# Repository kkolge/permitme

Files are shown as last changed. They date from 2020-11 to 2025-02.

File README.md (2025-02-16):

This product was developed during COVID-19 to 
1. Screen a large number of people based on 3 parameters - Temperature, Pulse Rate and SpO2
2. The purpose was to create a funnel where a large number of people can be screened in a short time so that probably infected people could be provided with a better care
3. The system uses this device as an IoT based data collection unit
4. It stored the data on a backend server which can be then checked during the next screening

The hardware system was developed in C, C++ and the web application was developed in PHP. 

Though this system was deployed at 30+ locations, it could not be scaled up due to delay in approvals during COVID. 

Unfortunately the Unit and Integration tests were lost in a system crash and are not part of the repository

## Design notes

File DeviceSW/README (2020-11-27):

This folder contains source code for the permit me device

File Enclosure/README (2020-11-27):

This folder contains Design files for the enclosure

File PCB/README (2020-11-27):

This folder contains KiCad Project for PCB

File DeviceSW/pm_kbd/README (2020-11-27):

This folder contains code for Keyboard device

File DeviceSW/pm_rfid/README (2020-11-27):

This folder contains code for permit me device with rfid reader

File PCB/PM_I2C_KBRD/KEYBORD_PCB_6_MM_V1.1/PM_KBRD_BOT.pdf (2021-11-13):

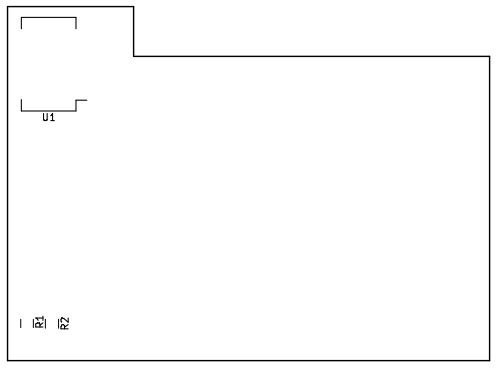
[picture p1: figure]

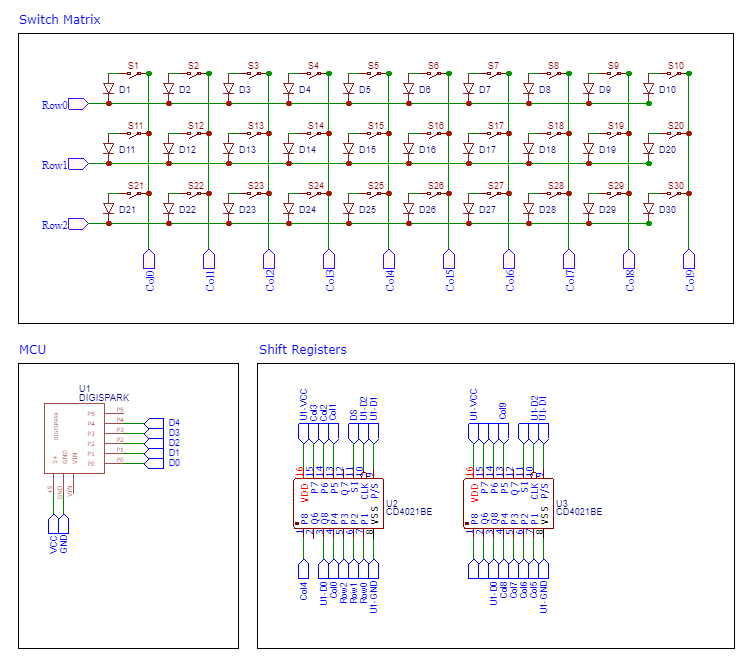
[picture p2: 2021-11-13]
PCB/PM_I2C_KBRD/KEYBORD_PCB_12MM_V4/F7GHN2HKNOLY77V.webp

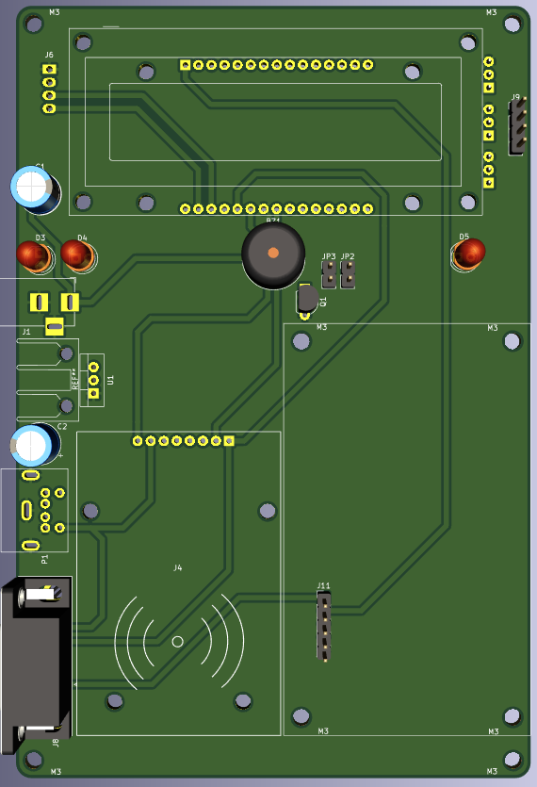
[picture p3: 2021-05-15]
PCB/Screenshot from 2020-12-09 14-33-55.png

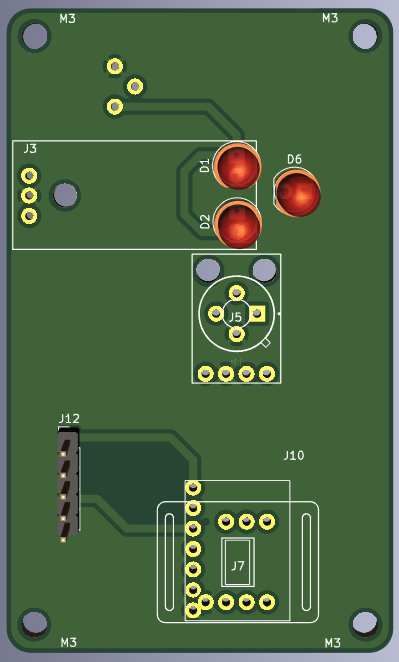
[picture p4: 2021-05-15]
PCB/Screenshot from 2020-12-09 14-36-24.png

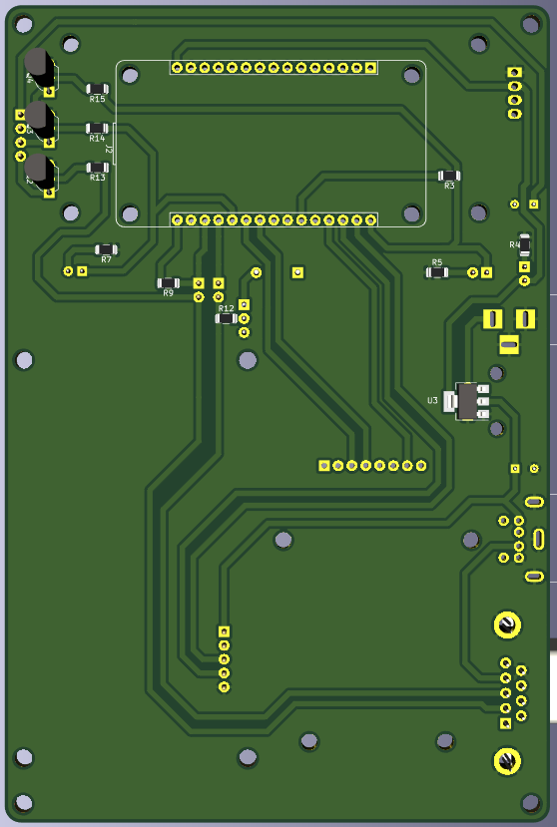
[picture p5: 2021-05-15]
PCB/Screenshot from 2020-12-09 14-34-07.png

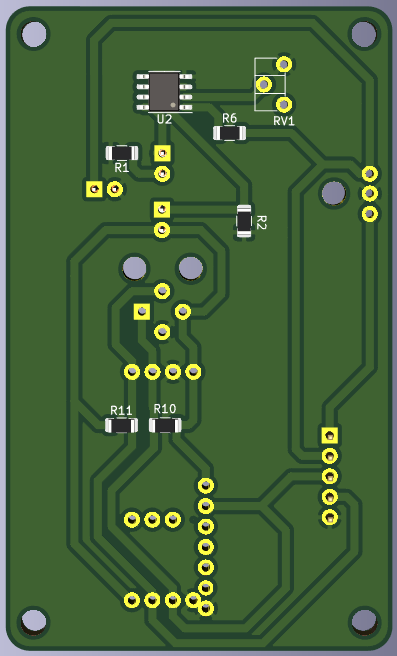
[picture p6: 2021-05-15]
PCB/Screenshot from 2020-12-09 14-36-14.png

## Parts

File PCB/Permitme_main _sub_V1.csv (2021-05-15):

Id | Designator | Package | Quantity | Designation
1 | BZ1 | Buzzer_12x9.5RM7.6 | 1 | 5V Buzzer
2 | C1 | CP_Radial_D8.0mm_P3.50mm | 1 | 100uf 16V
3 | C2 | CP_Radial_D8.0mm_P3.50mm | 1 | 470uf 16V
4 | D1 | LED_D5.0mm | 1 | IR_TX
5 | D2 | LED_D5.0mm | 1 | IR_RX
6 | D4 | LED_D5.0mm | 1 | RED LED 5MM
7 | D5 | LED_D5.0mm | 1 | GREEN LED 5MM
8 | J1 | BarrelJack_Horizontal | 1 | DC Barrel_Jack_Switch
9 | J11 | PinHeader_1x05_P2.54mm_Vertical | 1 | Female Burg Strip
10 | J12 | PinHeader_1x05_P2.54mm_Vertical | 1 | Male Burg Strip
11 | J2 | NODEMCU_LOLIN_V3 | 1 | ESP8266 Module
12 | J5 | MLX90614 | 1 | MLX90614
13 | J6 | WC1602A_I2C | 1 | I2C LCD
14 | J7 | MAX30102 | 1 | MAX30102
15 | JP2,JP3 | PinHeader_1x02_P2.54mm_Vertical | 2 | Jumper
16 | Q1 | TO-92L_Inline_Wide | 1 | BC548
17 | R1 | R_1206_3216Metric | 1 | 100E
18 | R11,R10 | R_1206_3216Metric | 2 | 220E
19 | R12 | R_1206_3216Metric | 1 | 1K
20 | R2 | R_1206_3216Metric | 1 | 10K
21 | R7,R3,R9,R5,R4,R6 | R_1206_3216Metric | 6 | 330E
22 | REF** | Heatsink16by35 | 1 | Heatsink16by35
23 | RV1 | Potentiometer_ACP_CA6-H2,5_Horizontal | 1 | 10K
24 | U2 | SOIC-8_3.9x4.9mm_P1.27mm | 1 | LM358
25 | P1 | Connector_Mini-DIN_Female_6Pin_2rows | 1 | PS2 FEMALE – 6pins
 |  | OR
 | J4 | RFID_MFRC522 | 1 | MFRC522
26 | U1 | TO-220-3_Vertical | 1 | LM1117-5.0
 |  | OR
 | U3 | SOT-223-3_TabPin2 | 1 | LM1117-5.0
 | Optinal
27 | D3,D6 | LED_D5.0mm | 2 | LED
28 | R14,R13,R15 | R_1206_3216Metric | 3 | 1K
29 | Q4,Q1,Q3,Q2 | TO-92L_Inline_Wide | 3 | BC548
30 | J8 | DSUB-9_Female_Horizontal | 1 | DB9_Female_MountingHoles

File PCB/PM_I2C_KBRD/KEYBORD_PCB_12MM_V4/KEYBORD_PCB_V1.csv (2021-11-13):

Id | Designator | Package | Quantity | Designation | Supplier and ref
1 | D1,D2,D3,D4,D5,D6,D7,D8 | D_DO-35_SOD27_P7.62mm_Horizontal | 8 | 1N4148
2 | J1 | PinSocket_1x08_P2.54mm_Vertical | 1 | Conn_01x08_Male
3 | R1,R2,R3,R4 | R_1206_3216Metric_Pad1.42x1.75mm_HandSolder | 4 | 5.6K
4 | R5 | R_1206_3216Metric_Pad1.42x1.75mm_HandSolder | 1 | 56K
5 | SW1 | SW_PUSH_6mm_H5mm | 1 | 1
6 | SW2 | SW_PUSH_6mm_H5mm | 1 | 4
7 | SW3 | SW_PUSH_6mm_H5mm | 1 | 7
8 | SW4 | SW_PUSH_6mm_H5mm | 1 | CLEAR
9 | SW5 | SW_PUSH_6mm_H5mm | 1 | 2
10 | SW6 | SW_PUSH_6mm_H5mm | 1 | 5
11 | SW7 | SW_PUSH_6mm_H5mm | 1 | 8
12 | SW8 | SW_PUSH_6mm_H5mm | 1 | 0
13 | SW9 | SW_PUSH_6mm_H5mm | 1 | 3
14 | SW10 | SW_PUSH_6mm_H5mm | 1 | 6
15 | SW11 | SW_PUSH_6mm_H5mm | 1 | 9
16 | SW12 | SW_PUSH_6mm_H5mm | 1 | ENTER
17 | U1 | SOIC-16_3.9x9.9mm_P1.27mm | 1 | 74HC595

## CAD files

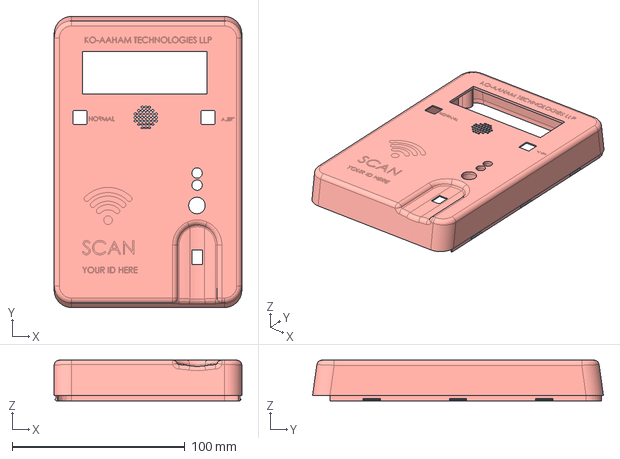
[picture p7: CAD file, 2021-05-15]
Enclosure/IDEMI/V4/outer_cover_ko-aham_tech_4.stp
108.7 x 168.6 x 23.6 mm

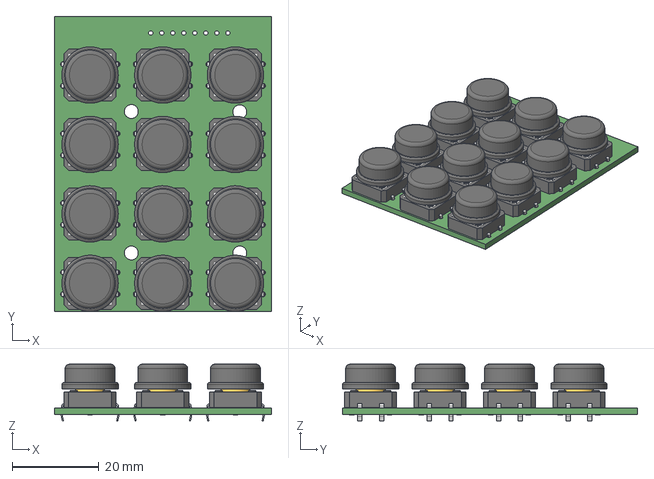
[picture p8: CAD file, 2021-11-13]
PCB/PM_I2C_KBRD/KEYBORD_PCB_12MM_V4/KEYBORD_PCB_V1.step
50.0 x 68.0 x 13.0 mm

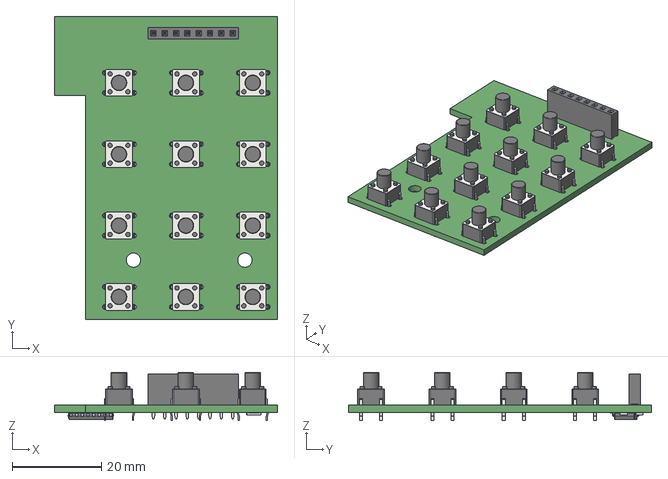
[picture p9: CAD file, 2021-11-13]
PCB/PM_I2C_KBRD/KEYBORD_PCB_6_MM_V1.1/EXPORT/STEP/KEYBORD_PCB_V1.step
50.0 x 68.0 x 10.8 mm

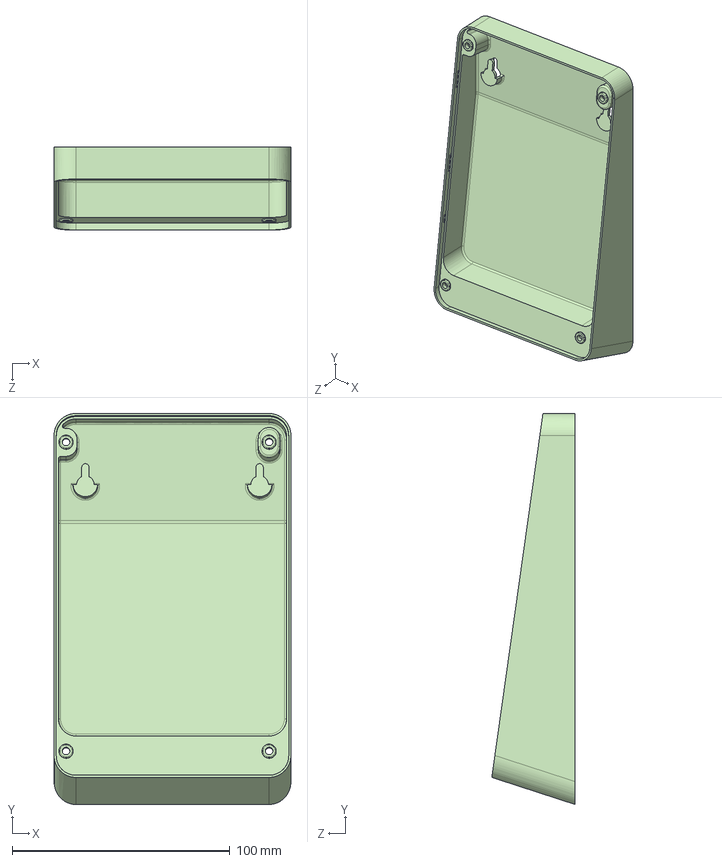
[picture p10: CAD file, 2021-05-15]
Enclosure/IDEMI/V4/back_cover_ko-aham_tech_4.IGS
108.7 x 179.4 x 38.3 mm

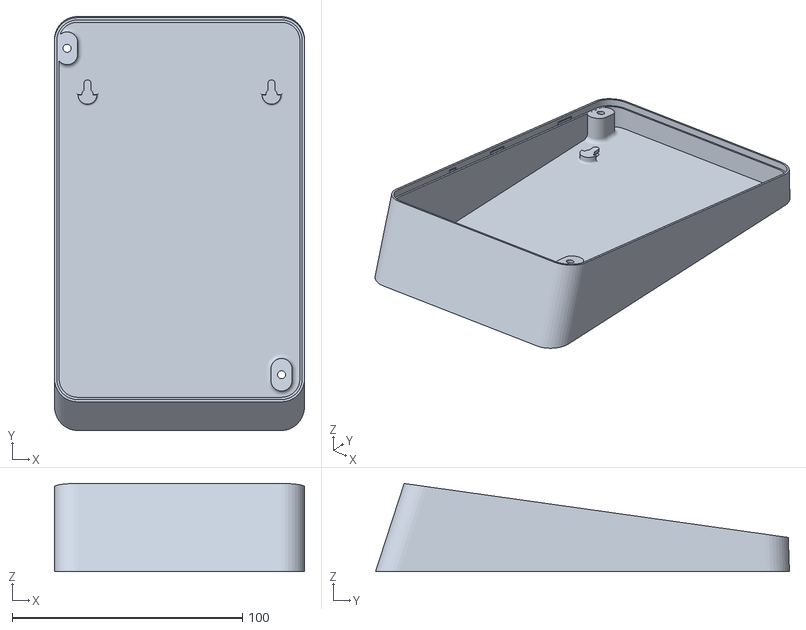
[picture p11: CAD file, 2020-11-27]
Enclosure/IDEMI/V4/KOAHAM D8.1 - BACK COVER KO-AHAM TECH 4-1.STL
108.7 x 180.0 x 38.3

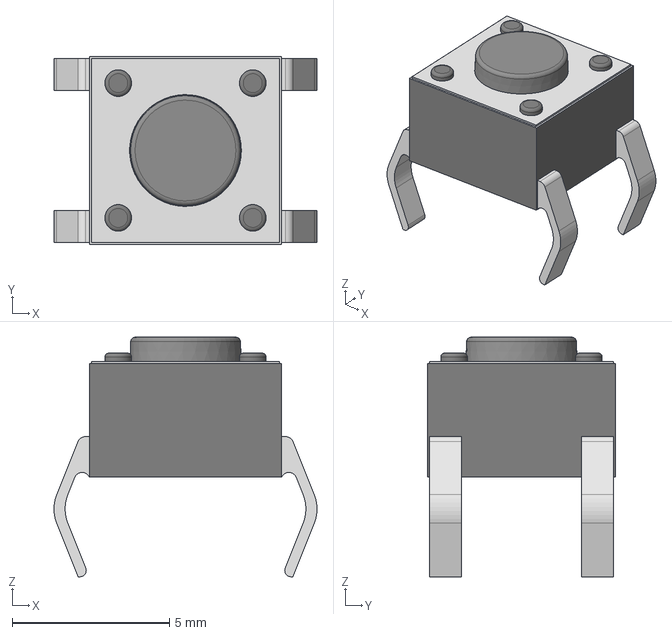
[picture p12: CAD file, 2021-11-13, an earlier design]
PCB/PM_I2C_KBRD/KEYBORD_PCB_6_MM_V1/3D/tactile-switch-thru-6mm-series-1.snapshot.25/Tactal Switch -Thru (6mmx 6mmx4.5mm).stp
8.37 x 5.99 x 7.62 mm

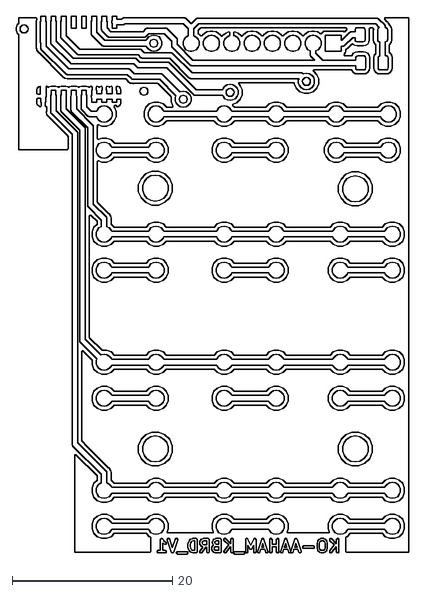
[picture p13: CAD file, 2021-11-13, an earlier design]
PCB/PM_I2C_KBRD/KEYBORD_PCB_6_MM_V1/Gurber-dxf/KEYBORD_PCB_V1-B.Cu.dxf
49.1 x 67.2

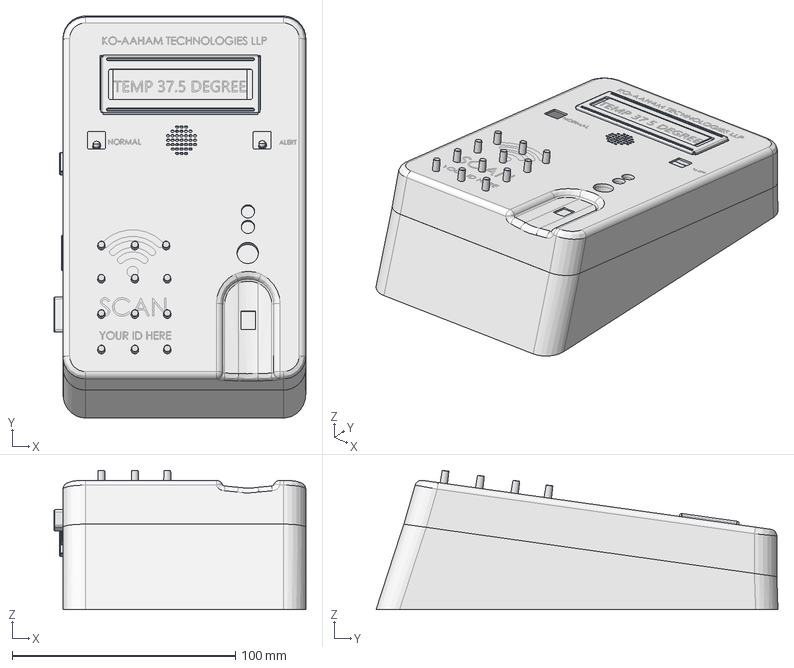
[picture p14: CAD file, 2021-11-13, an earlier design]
PCB/PM_I2C_KBRD/KEYBORD_PCB_6_MM_V1/OLD EXPORT/new keypad_/new keypad with encloser.FCStd
112.6 x 180.0 x 62.4 mm
BACK COVER KO-AHAM TECH 4
OUTER COVER KO-AHAM TECH 4
TEMPRATURE PLATE
SOLID.step
SOLID001.step
SOLID002.step
SOLID003.step
SOLID004.step
SOLID006.step
SOLID007.step
SOLID008.step
SOLID009.step
SOLID010.step
SOLID011.step
SOLID012.step
SOLID013.step
SOLID014.step
SOLID015.step
SOLID016.step
SOLID017.step
SOLID018.step
SOLID019.step
SOLID020.step
SOLID021.step
SOLID022.step
SOLID023.step
SOLID024.step
SOLID025.step
SOLID026.step
SOLID028.step
SOLID029.step
COMPOUND.step
13-FreeParts

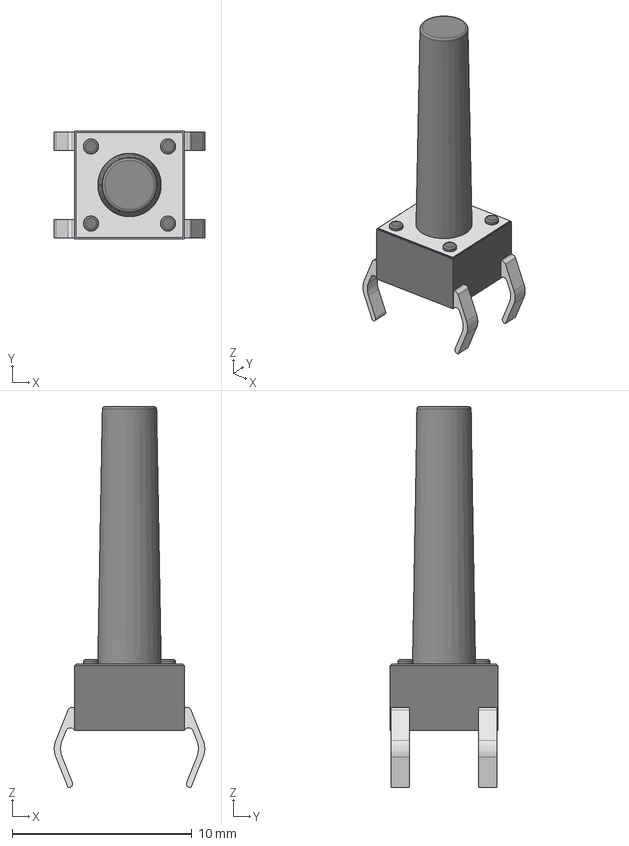
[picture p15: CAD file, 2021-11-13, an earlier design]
PCB/PM_I2C_KBRD/KEYBORD_PCB_6_MM_V1/3D/tactile-switch-thru-6mm-series-1.snapshot.25/Tactal Switch -Thru (6mmx 6mmx18.0mm).stp
8.37 x 5.99 x 21.2 mm

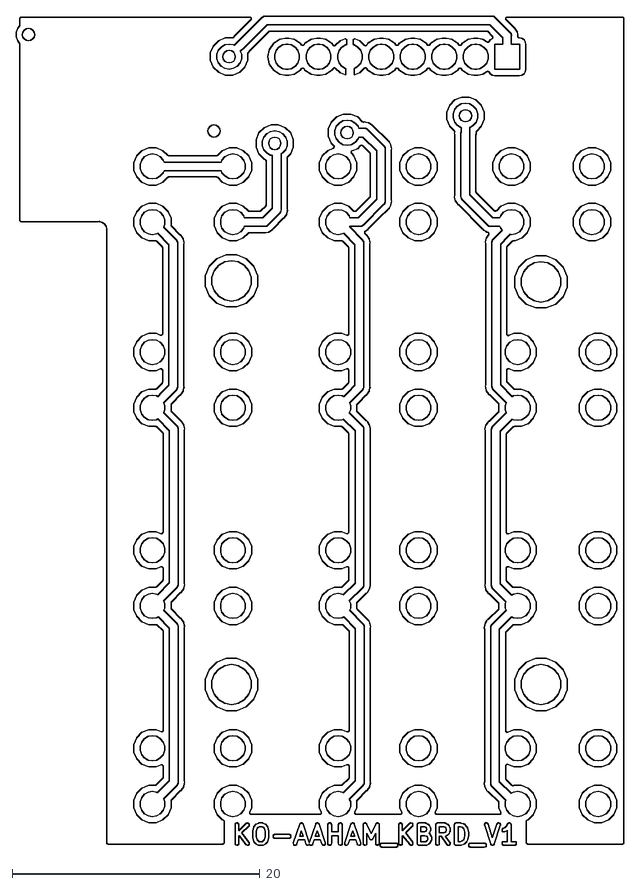
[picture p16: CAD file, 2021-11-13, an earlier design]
PCB/PM_I2C_KBRD/KEYBORD_PCB_6_MM_V1/Gurber-dxf/KEYBORD_PCB_V1-F.Cu.dxf
49.1 x 67.1

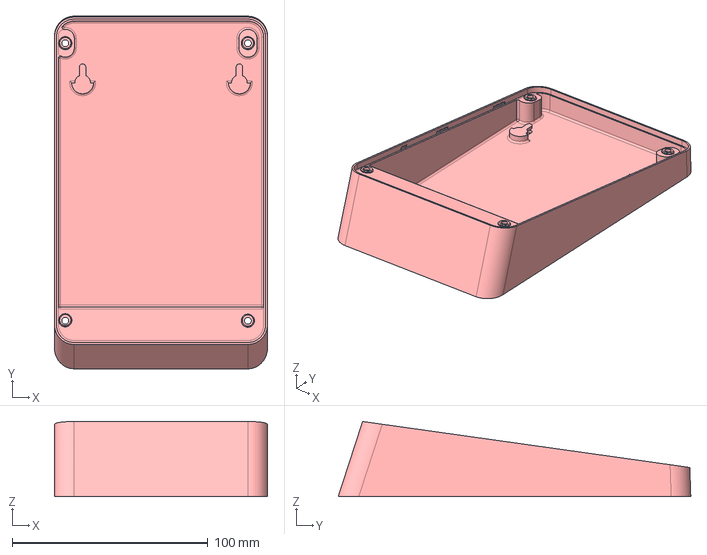
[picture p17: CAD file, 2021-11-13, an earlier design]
PCB/PM_I2C_KBRD/KEYBORD_PCB_6_MM_V1/OLD EXPORT/BACK COVER .stp
108.7 x 180.0 x 38.3 mm

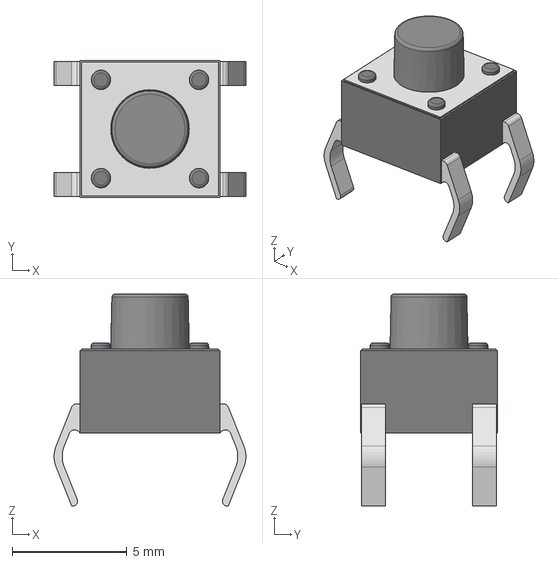
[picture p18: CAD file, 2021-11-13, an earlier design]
PCB/PM_I2C_KBRD/KEYBORD_PCB_6_MM_V1/3D/tactile-switch-thru-6mm-series-1.snapshot.25/Tactal Switch -Thru (6mmx 6mmx6.0mm).stp
8.37 x 5.99 x 9.25 mm

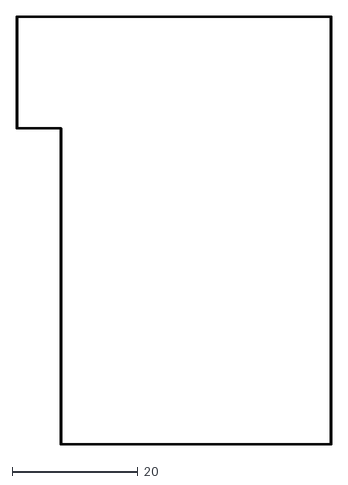
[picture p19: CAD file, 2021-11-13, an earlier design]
PCB/PM_I2C_KBRD/KEYBORD_PCB_6_MM_V1/Gurber-dxf/KEYBORD_PCB_V1-Edge.Cuts.dxf
50.2 x 68.2

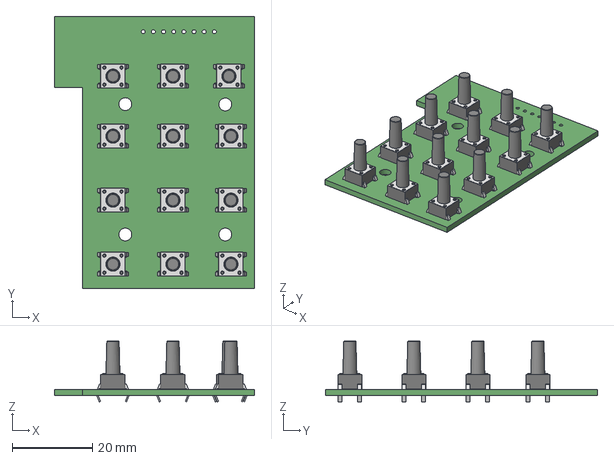
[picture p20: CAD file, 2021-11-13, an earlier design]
PCB/PM_I2C_KBRD/KEYBORD_PCB_6_MM_V1/OLD EXPORT/KEYBORD_PCB_V1.step
50.0 x 68.0 x 15.2 mm

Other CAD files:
PCB/PM_I2C_KBRD/KEYBORD_PCB_6_MM_V1/EXPORT/KEYBORD_PCB_V1.step
PCB/PM_I2C_KBRD/KEYBORD_PCB_6_MM_V1/OLD EXPORT/OUTER COVER.stp
PCB/PM_I2C_KBRD/KEYBORD_PCB_6_MM_V1/3D/tactile-switch-thru-6mm-series-1.snapshot.25/Tactal Switch -Thru (6mmx 6mmx14.0mm).stp
PCB/PM_I2C_KBRD/KEYBORD_PCB_6_MM_V1/3D/tactile-switch-thru-6mm-series-1.snapshot.25/Tactal Switch -Thru (6mmx 6mmx4.3mm).stp
Enclosure/IDEMI/V4/back_cover_ko-aham_tech_4.STL
Enclosure/IDEMI/V4/outer_cover_ko-aham_tech_4.stl
PCB/PM_I2C_KBRD/KEYBORD_PCB_6_MM_V1/3D/tactile-switch-thru-6mm-series-1.snapshot.25/Tactal Switch -Thru (6mmx 6mmx10.0mm).stp
PCB/PM_I2C_KBRD/KEYBORD_PCB_6_MM_V1/3D/tactile-switch-thru-6mm-series-1.snapshot.25/Tactal Switch -Thru (6mmx 6mmx11.0mm).stp
PCB/PM_I2C_KBRD/KEYBORD_PCB_6_MM_V1/3D/tactile-switch-thru-6mm-series-1.snapshot.25/Tactal Switch -Thru (6mmx 6mmx12.0mm).stp
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

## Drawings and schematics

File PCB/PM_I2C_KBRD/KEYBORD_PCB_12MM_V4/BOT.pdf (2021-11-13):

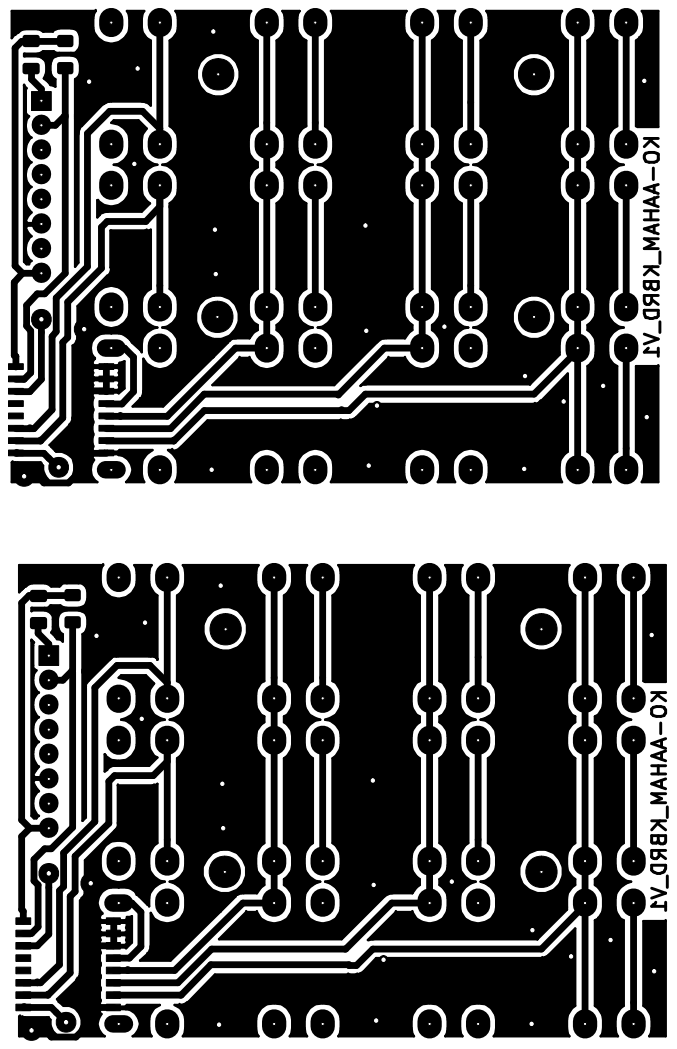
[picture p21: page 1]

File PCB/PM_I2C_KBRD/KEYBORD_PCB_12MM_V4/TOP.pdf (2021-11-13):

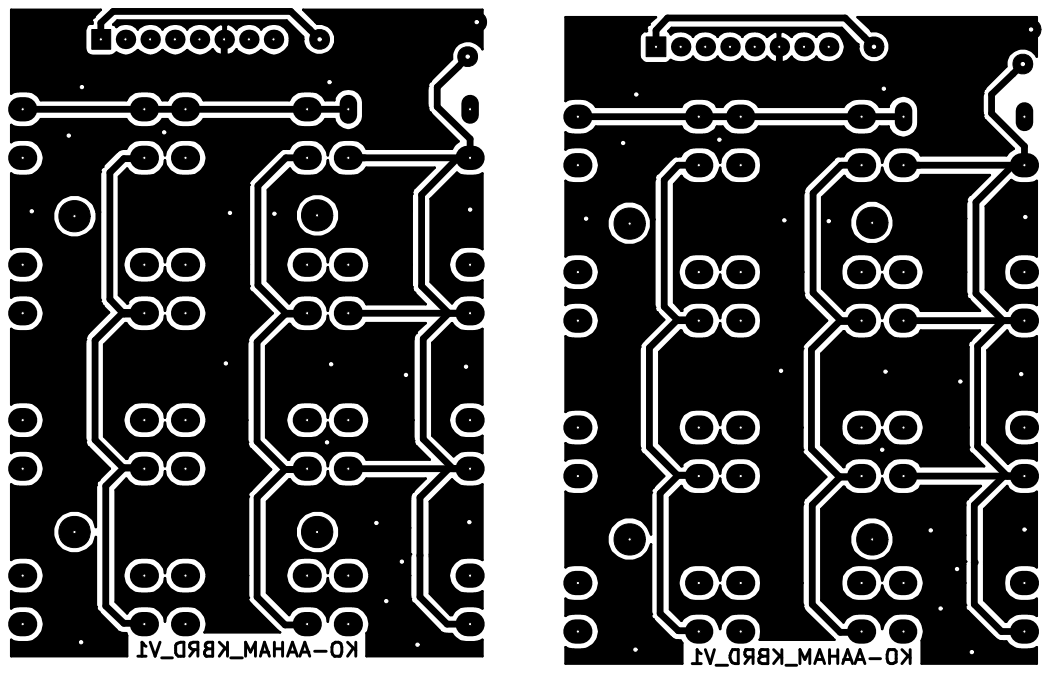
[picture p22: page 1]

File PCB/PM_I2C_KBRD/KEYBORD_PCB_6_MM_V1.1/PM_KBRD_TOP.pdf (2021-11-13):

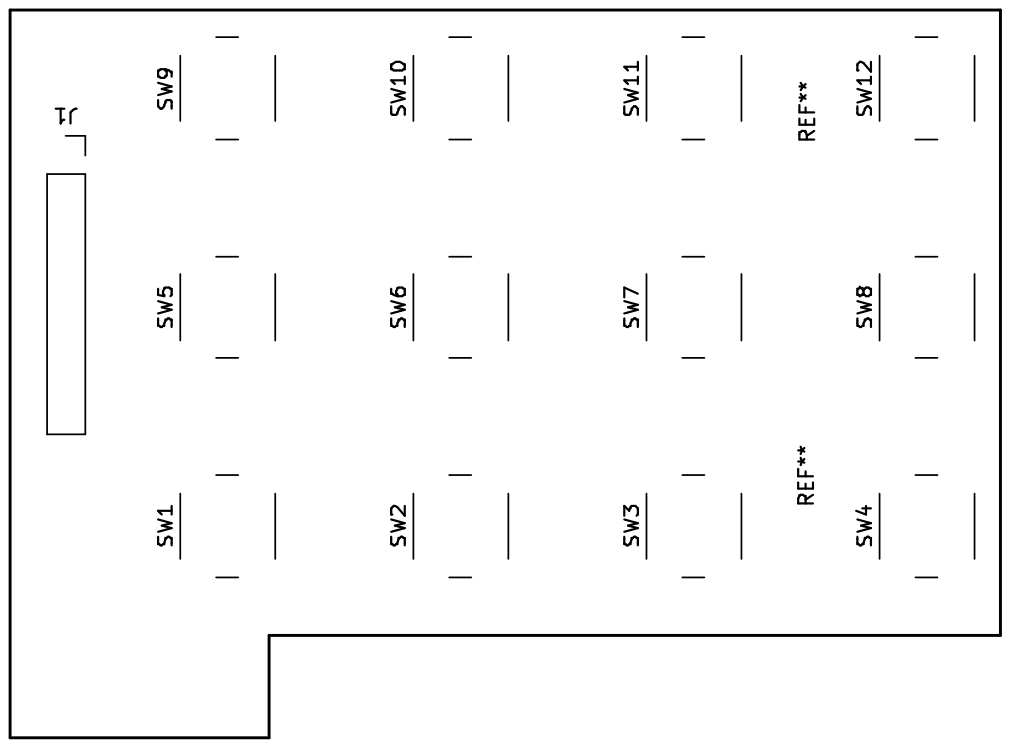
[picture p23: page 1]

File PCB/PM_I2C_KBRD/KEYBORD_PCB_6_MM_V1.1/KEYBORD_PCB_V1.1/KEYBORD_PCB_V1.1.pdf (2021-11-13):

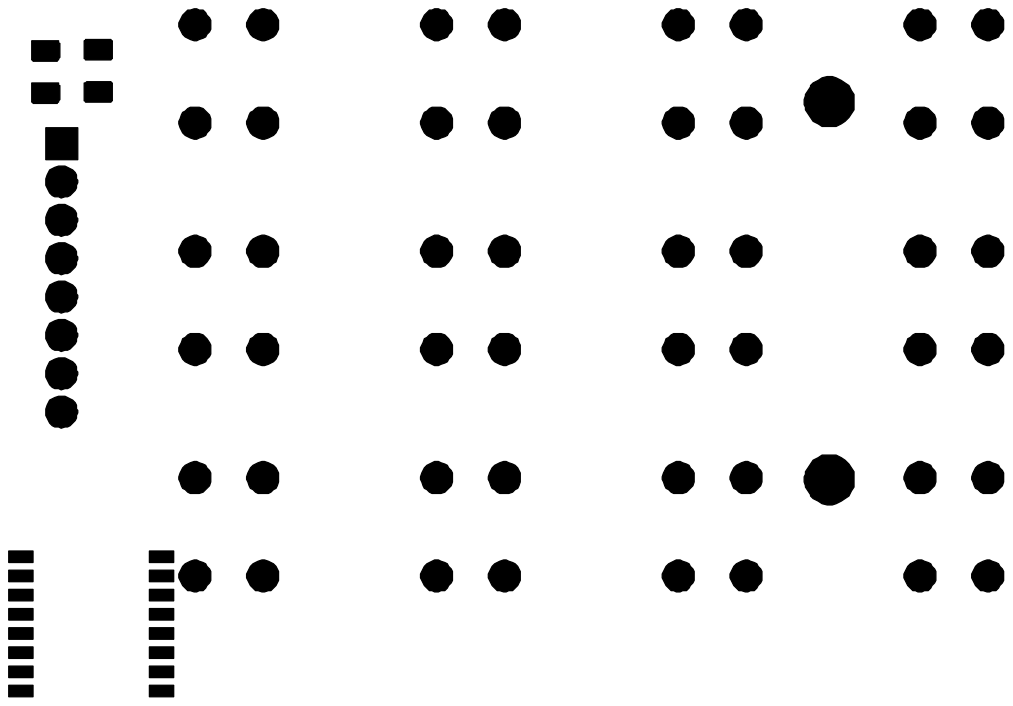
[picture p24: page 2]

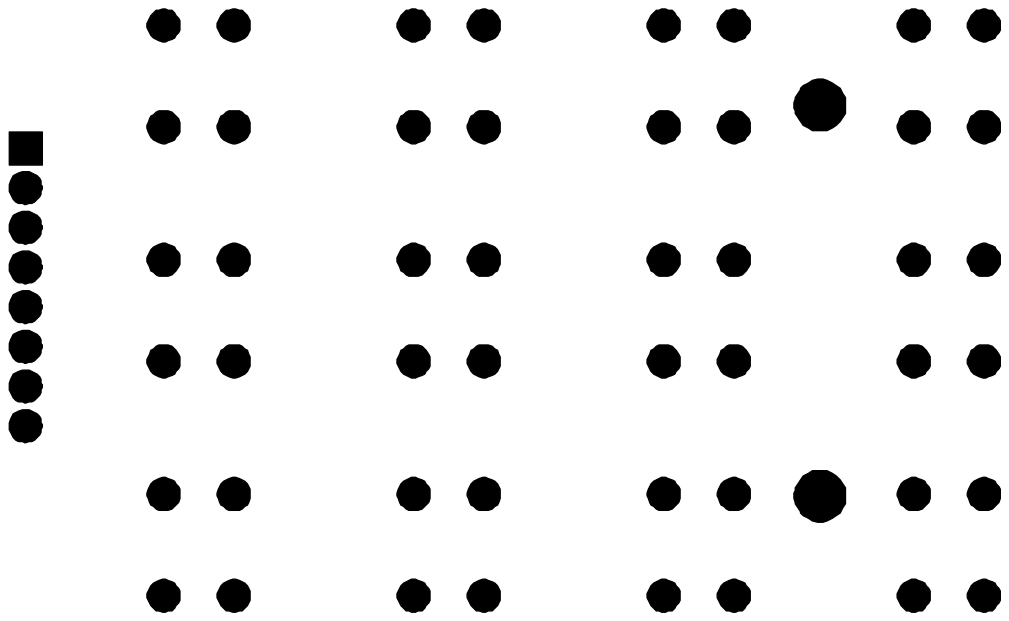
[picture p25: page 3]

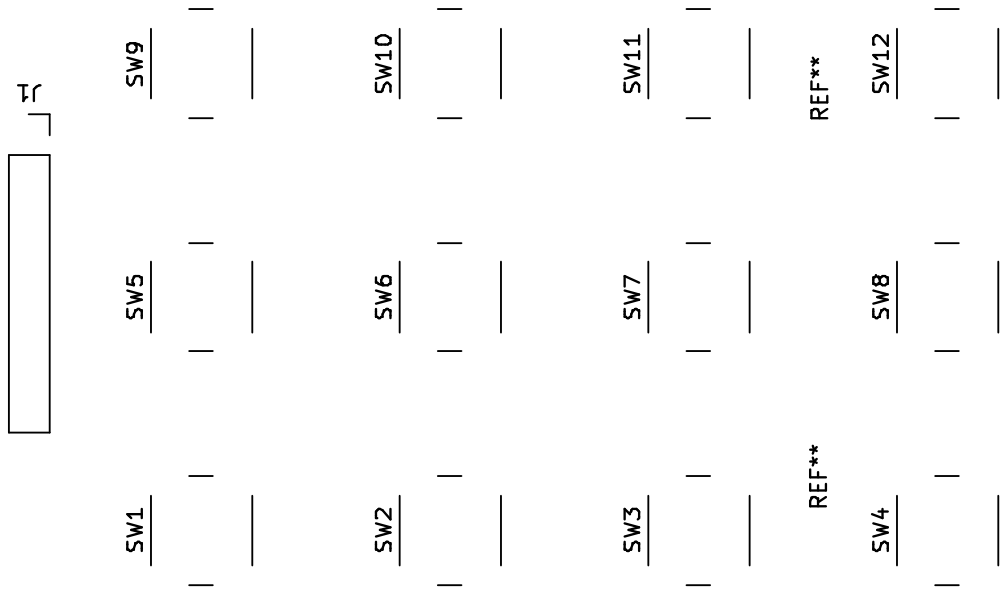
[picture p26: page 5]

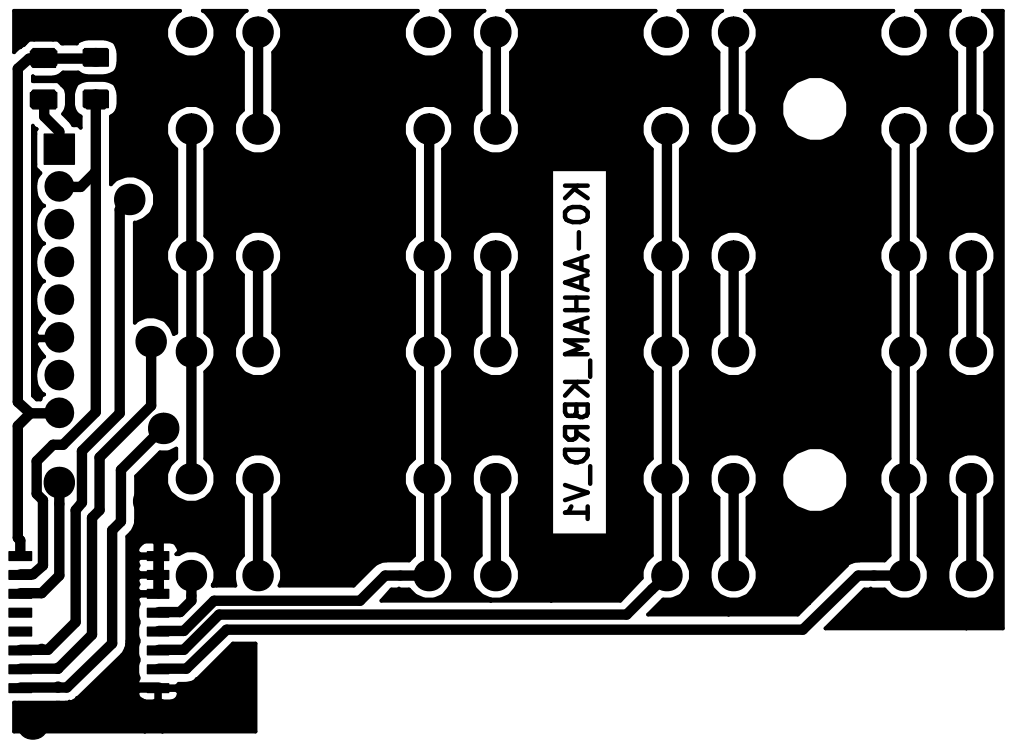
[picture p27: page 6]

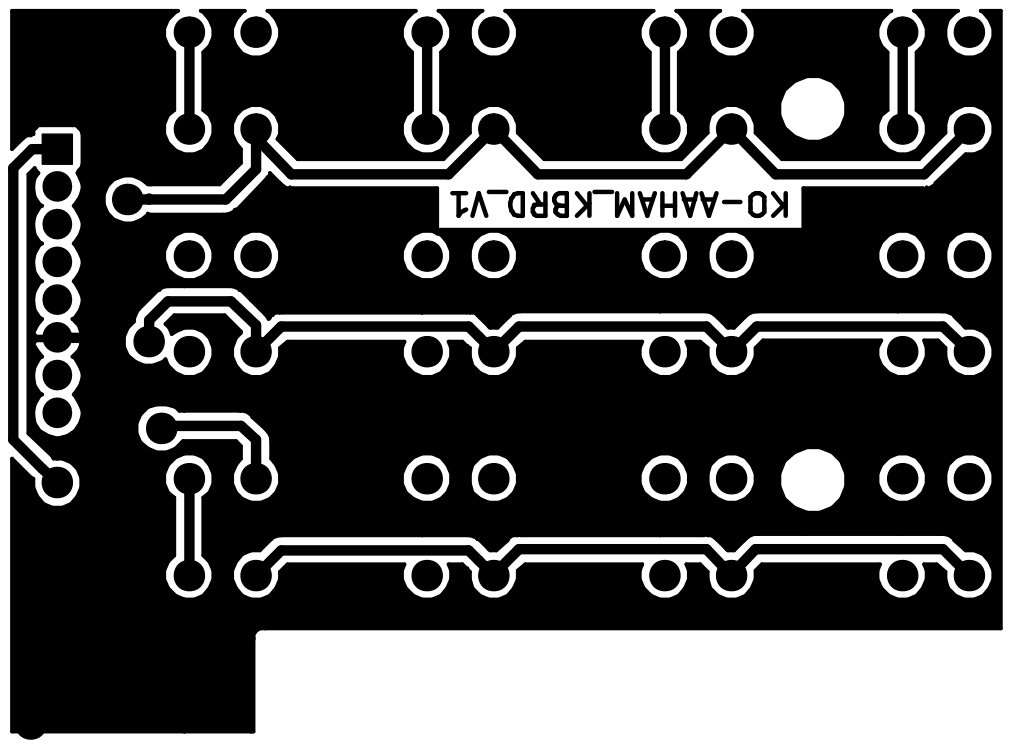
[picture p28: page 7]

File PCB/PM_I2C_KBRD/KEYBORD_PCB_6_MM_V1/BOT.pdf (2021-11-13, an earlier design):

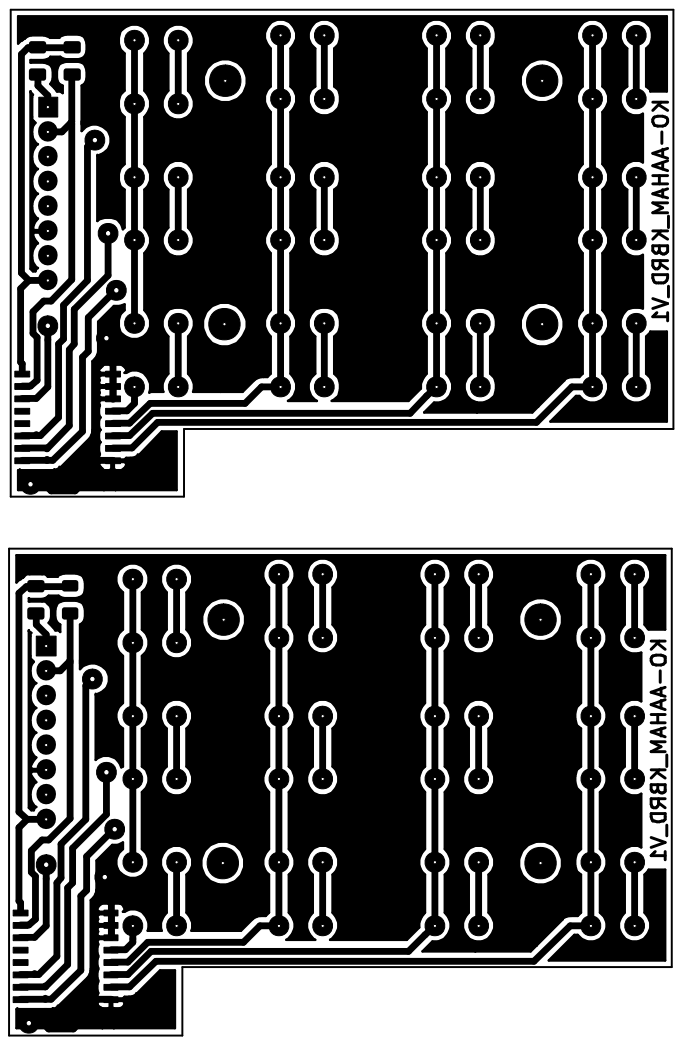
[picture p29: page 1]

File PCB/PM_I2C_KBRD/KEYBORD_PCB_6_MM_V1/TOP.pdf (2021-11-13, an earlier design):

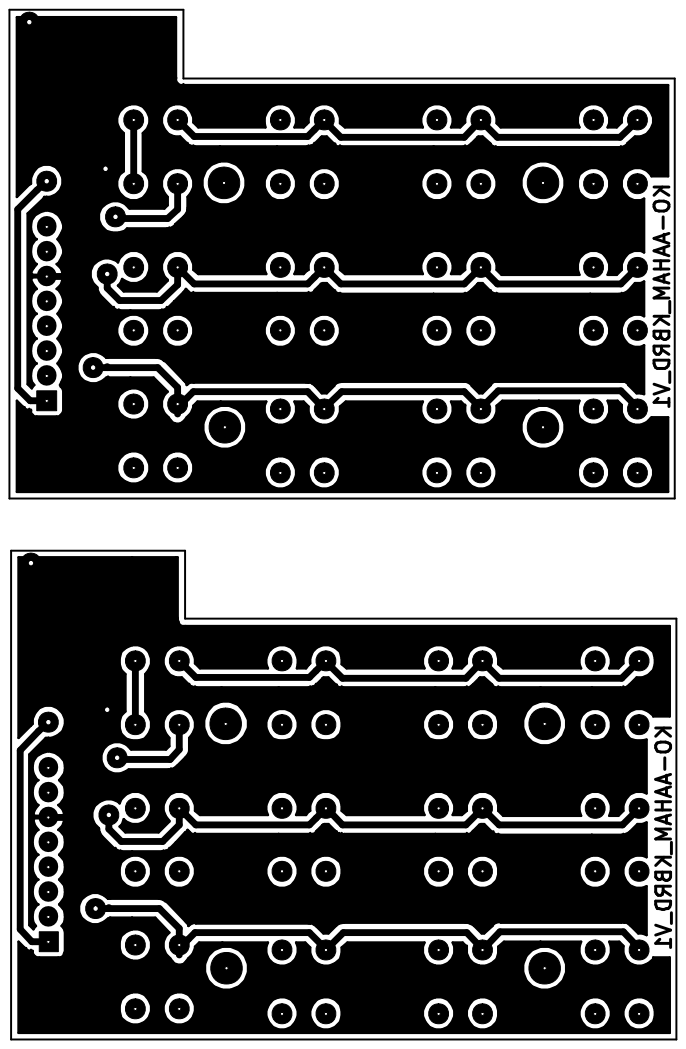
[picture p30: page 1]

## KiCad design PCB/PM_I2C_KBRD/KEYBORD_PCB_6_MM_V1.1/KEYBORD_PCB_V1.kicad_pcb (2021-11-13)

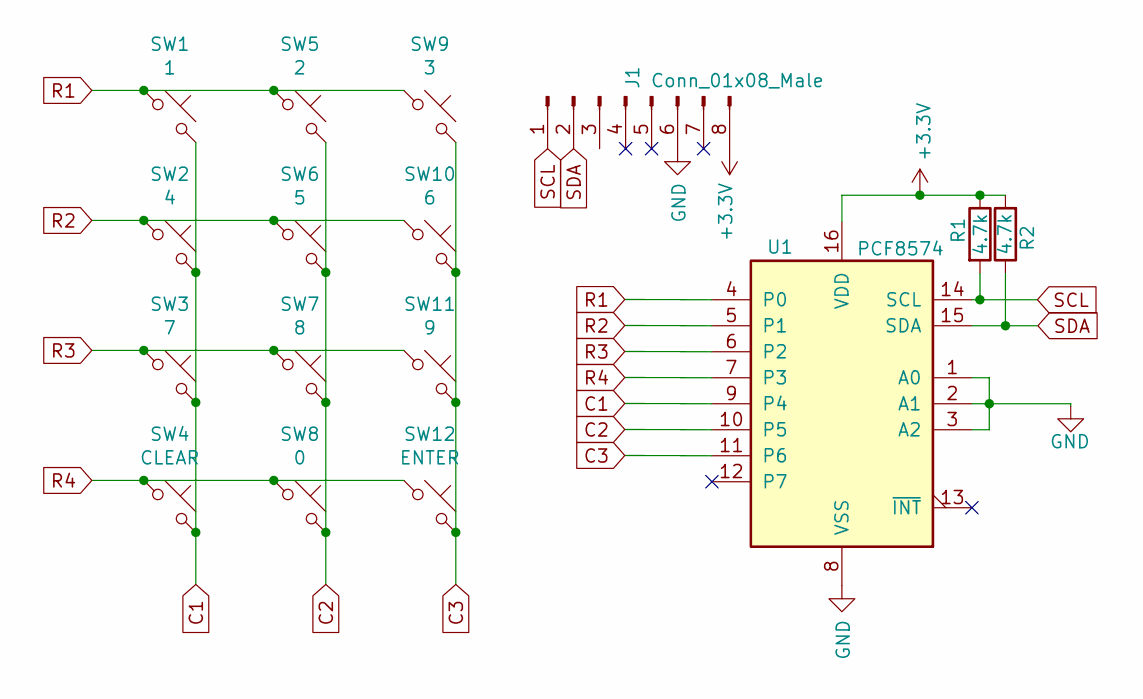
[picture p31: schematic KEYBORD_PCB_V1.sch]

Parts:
J1: Conn_01x08_Male; PinSocket_1x08_P2.54mm_Vertical
R1, R2: 4.7k; R_1206_3216Metric
SW1: 1; SW_PUSH_6mm_H7.3mm
SW2: 4; SW_PUSH_6mm_H7.3mm
SW3: 7; SW_PUSH_6mm_H7.3mm
SW4: CLEAR; SW_PUSH_6mm_H7.3mm
SW5: 2; SW_PUSH_6mm_H7.3mm
SW6: 5; SW_PUSH_6mm_H7.3mm
SW7: 8; SW_PUSH_6mm_H7.3mm
SW8: 0; SW_PUSH_6mm_H7.3mm
SW9: 3; SW_PUSH_6mm_H7.3mm
SW10: 6; SW_PUSH_6mm_H7.3mm
SW11: 9; SW_PUSH_6mm_H7.3mm
SW12: ENTER; SW_PUSH_6mm_H7.3mm
U1: PCF8574; SOIC-16W_7.5x12.8mm_P1.27mm

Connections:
+3V3: J1.8, R1.1, R2.2, U1.16 (VDD)
C1: SW1.2, SW2.2, SW3.2, SW4.2, U1.9 (P4)
C2: SW5.2, SW6.2, SW7.2, SW8.2, U1.10 (P5)
C3: SW9.2, SW10.2, SW11.2, SW12.2, U1.11 (P6)
GND: J1.6, U1.1 (A0), U1.2 (A1), U1.3 (A2), U1.8 (VSS)
R1: SW1.1, SW5.1, SW9.1, U1.4 (P0)
R2: SW2.1, SW6.1, SW10.1, U1.5 (P1)
R3: SW3.1, SW7.1, SW11.1, U1.6 (P2)
R4: SW4.1, SW8.1, SW12.1, U1.7 (P3)
SCL: J1.1, R1.2, U1.14 (SCL)
SDA: J1.2, R2.1, U1.15 (SDA)

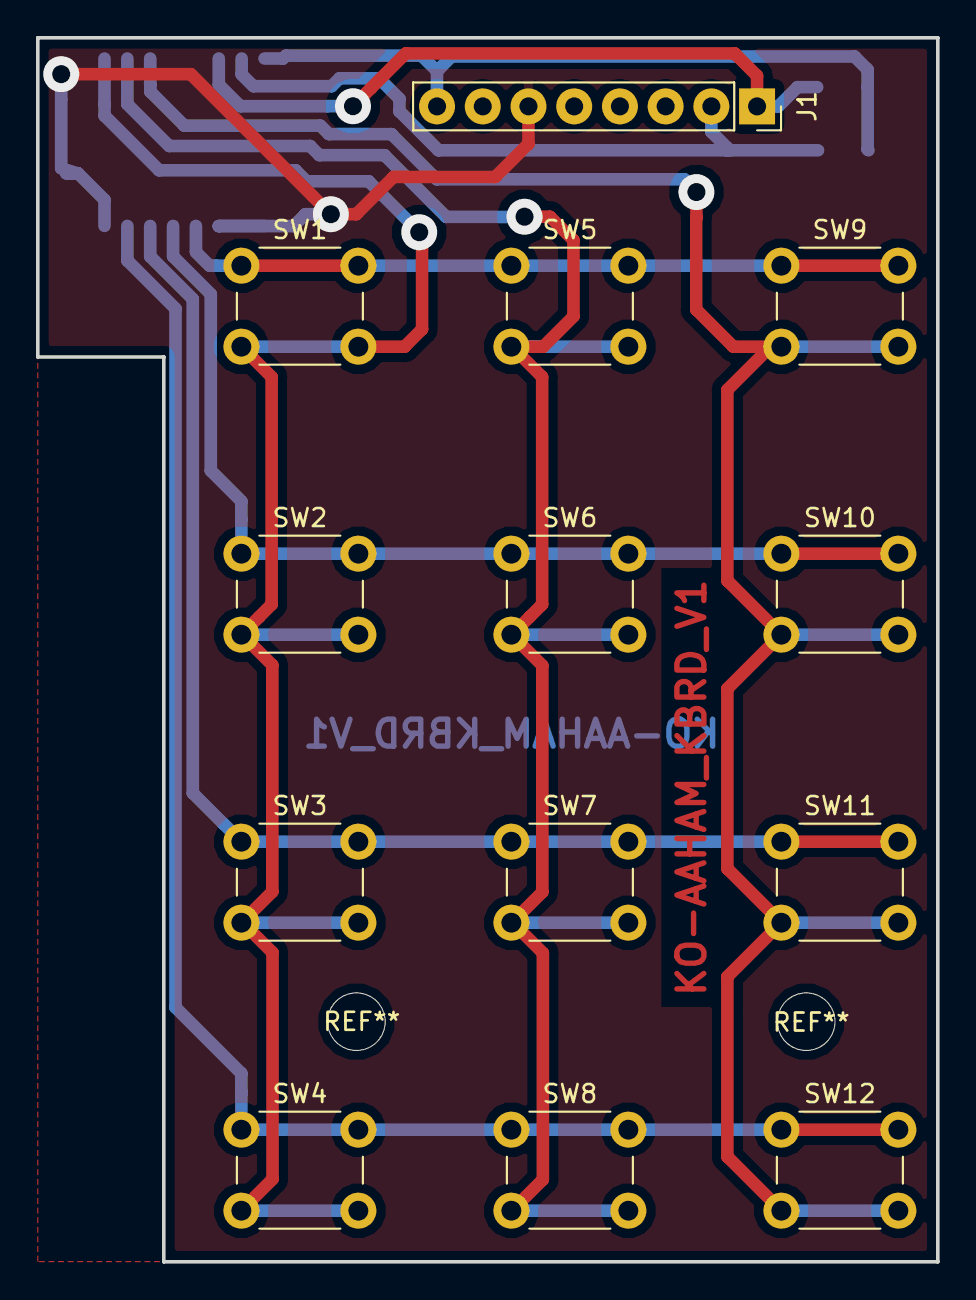
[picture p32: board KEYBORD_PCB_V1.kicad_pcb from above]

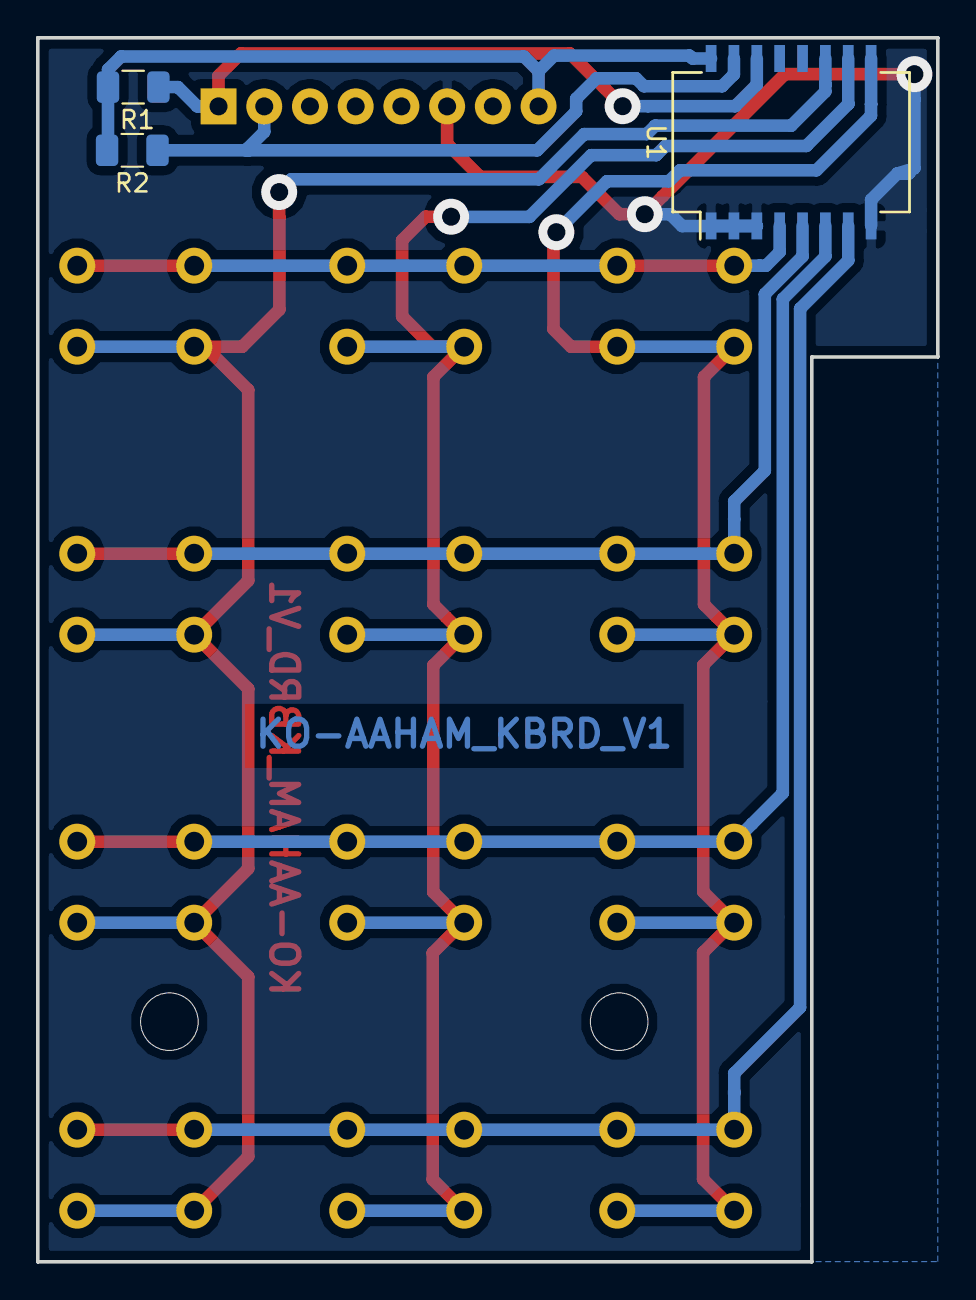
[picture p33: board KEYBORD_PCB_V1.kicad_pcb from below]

Board: 2 copper layers, 50.0 x 68.0 mm, 16 parts (3 on the bottom side), 11 nets.

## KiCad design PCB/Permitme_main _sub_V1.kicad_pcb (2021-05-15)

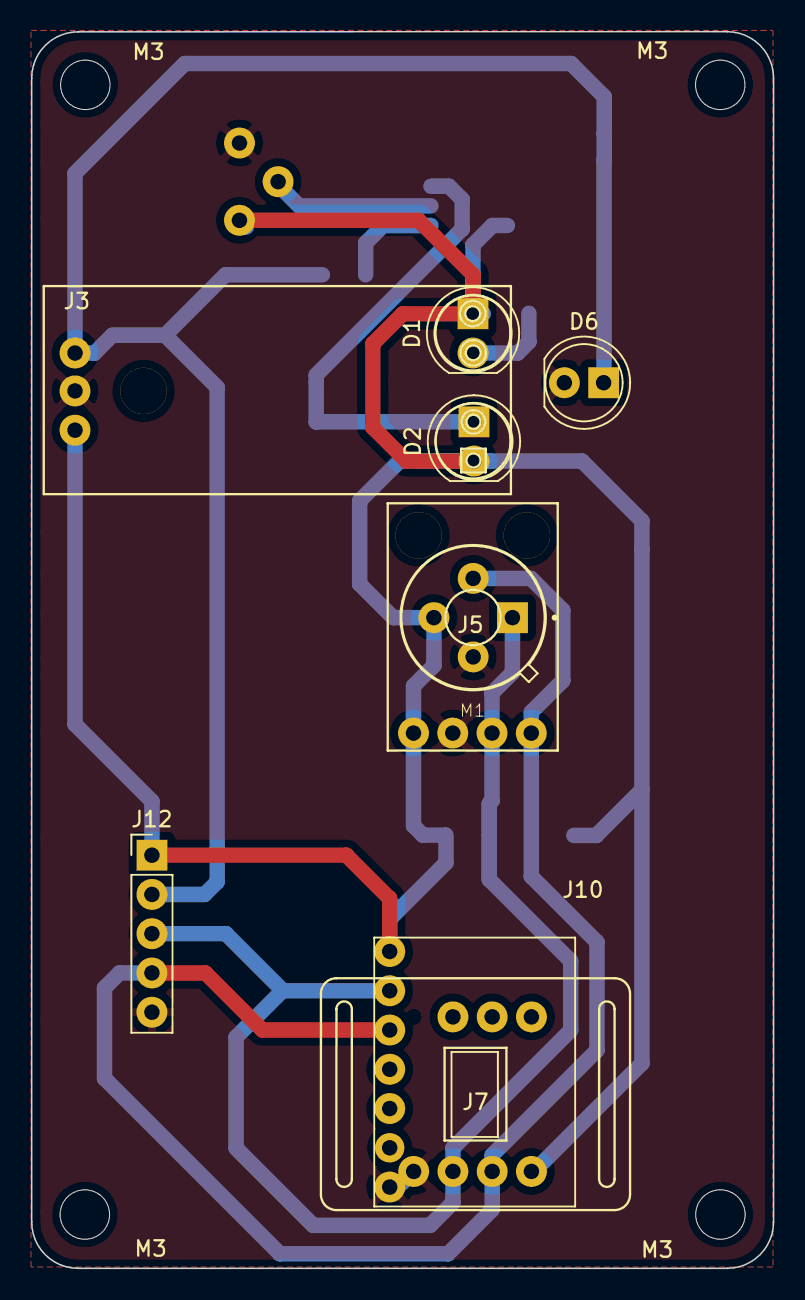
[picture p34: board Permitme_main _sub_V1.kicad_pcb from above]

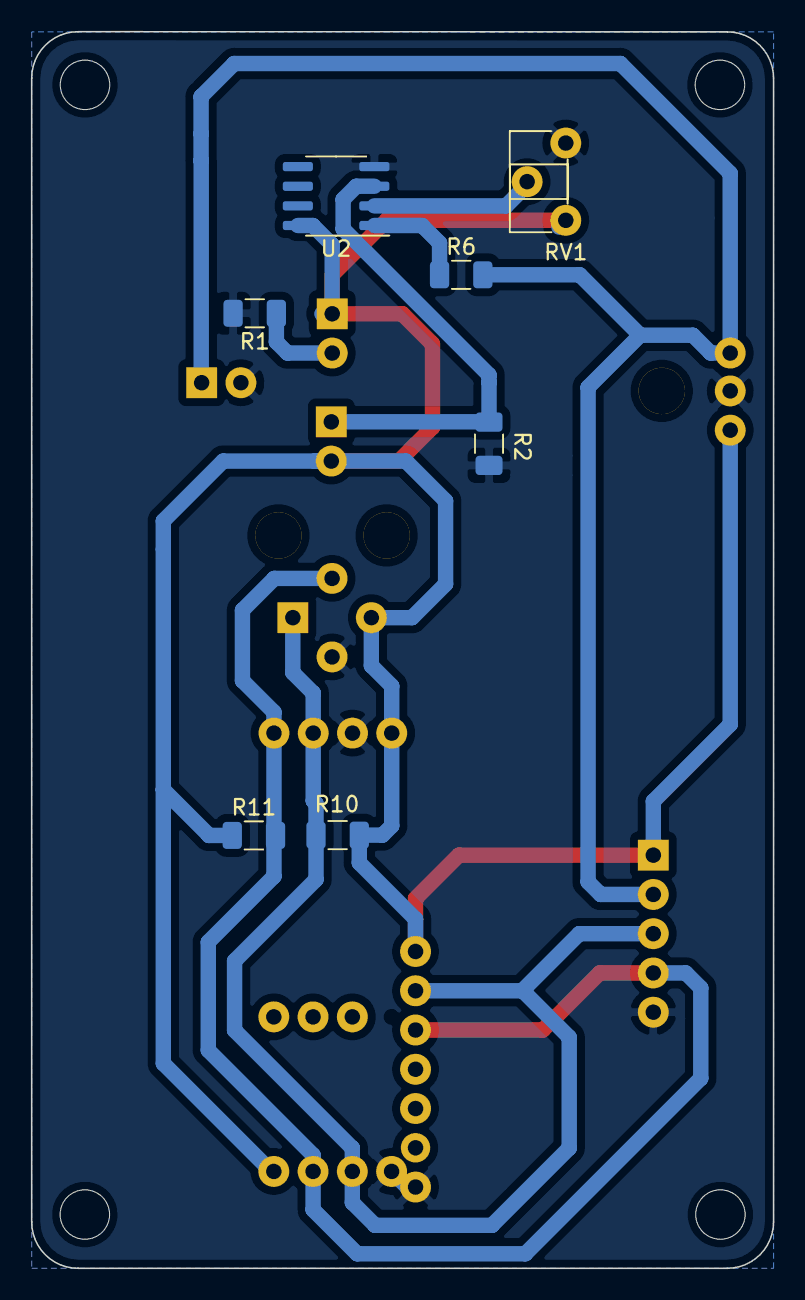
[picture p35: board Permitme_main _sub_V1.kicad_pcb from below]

Board: 2 copper layers, 48.0 x 80.0 mm, 20 parts (7 on the bottom side), 9 nets.

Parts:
D1: LED_ALT; LED_D5.0mm
D2: D_Photo_ALT; LED_D5.0mm
D6: LED; LED_D5.0mm
J3: IR Sensor
J5: MLX90614
J7: MAX30102
J10: MAX30102_1
J12: Conn_01x05_Male; PinHeader_1x05_P2.54mm_Vertical
M1: MLX90614ESF-DCA-000-TU; TO254P942H425-4
M3, M3#2, M3#3, M3#4: MountingHole_3.2mm_M3
R1: 100E; R_1206_3216Metric
R2: 10K; R_1206_3216Metric
R6: 330E; R_1206_3216Metric
R10, R11: 220E; R_1206_3216Metric
RV1: 10K; Potentiometer_ACP_CA6-H2,5_Horizontal
U2: LM358; SOIC-8_3.9x4.9mm_P1.27mm

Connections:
+5VA: D1.2, D2.1, J3.3, J5.1, J7.4, J10.1, J12.1, M1.3, R10.1, R11.1, RV1.1, U2.8
GNDA: D6.1, J3.2, J5.2, J7.1, J10.7, J12.5, M1.4, R1.2, R2.2, RV1.3, U2.4
IR1: D6.2, J3.1, J12.2, R6.2
unnamed: D1.1, R1.1
unnamed: D2.2, R2.1, U2.3
unnamed: R6.1, U2.1
unnamed: RV1.2, U2.2
SCL1: J5.3, J7.2, J10.2, J12.3, M1.1, R10.2
SDA1: J5.4, J7.3, J10.3, J12.4, M1.2, R11.2

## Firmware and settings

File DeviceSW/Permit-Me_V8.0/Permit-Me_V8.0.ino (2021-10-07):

#include <ESP8266WiFi.h>
#include <CertStoreBearSSL.h>
#include <ESP8266HTTPClient.h>
#include <ESP8266httpUpdate.h>
#include <ESP8266WebServer.h>
#include <EEPROM.h>
#include <Wire.h>
#include <time.h>
#include <FS.h>
#include <ArduinoJson.h>  //{"Deviceid":"DEVKODEMO17","Tocken":"0000000000000000","LCD":39} dec 39 = hex 27 dec 63 = hex 3F

#include "MAX30102.h"
#include "Pulse.h"
#include "LiquidCrystal_I2C.h"
#include "MLX90614.h"
#include "MD5.h"

const int httpPort = 80;                     //http port for fw update
String VERSION = "1.0.0";                    //fw version
String MODEL = "1";                          // not in use

// const char* host = "192.168.49.50";           // server address for FW update
const char* fwURLLoc = "/fw_update/";         // server pa for FW update

//#define _DEBUG      // UNCOMMENT FOR DEBUGGING/////////////////////////////


//#define _KBRD     // COMMENT FOR RFID INTERFACE UNCOMMENT FOR KEYBORD INTERFACE /////////////////////


String visit = "Pls visit doctor";  //LCD Display String if abnormal

int scan_delay = 500;              // 500 ms x numReadings

int restart_in = 5;               //restart counter 5 sec




#ifdef _KBRD
String devType = "KBRD";
#include "SoftwareI2C.h"
SoftwareI2C WireS1;

#include "Keypad_I2C.h"
#include "Keypad.h"

#define I2CADDR 0x20

#define SDA_PIN D5
#define SCL_PIN D4

const byte ROWS = 4; //four rows
const byte COLS = 3; //three columns
char keys[ROWS][COLS] = {
  {'1', '2', '3'},
  {'4', '5', '6'},
  {'7', '8', '9'},
  {'C', '0', 'E'}
};

// Digitran keypad, bit numbers of PCF8574 i/o port
byte rowPins[ROWS] = {0, 1, 2, 3}; //connect to the row pinouts of the keypad
byte colPins[COLS] = {4, 5, 6}; //connect to the column pinouts of the keypad

Keypad_I2C kpd( makeKeymap(keys), rowPins, colPins, ROWS, COLS, I2CADDR, PCF8574 );


#else

#include <SPI.h>
#include "MFRC522.h"
#define SS_PIN D4
#define RST_PIN D3
String devType = "RFID";
MFRC522 mfrc522(SS_PIN, RST_PIN);   // Create MFRC522 instance.

#endif



byte x, y;  // track lcd position
char c;
char MobNo[11] = " ";

LiquidCrystal_I2C lcd(16, 2); // set the LCD 16 chars and 2 line display

String deviceid;  // = "DEVKOTEST1";      // DEV-KO-001  ko-aaham office

MLX90614 mlx = MLX90614();
MAX30102 sensor;
Pulse pulseIR;
Pulse pulseRed;
MAFilter bpm;

//spo2_table is approximated as  -45.060*ratioAverage* ratioAverage + 30.354 *ratioAverage + 94.845 ;
const uint8_t spo2_table[184] PROGMEM =
{ 95, 95, 95, 96, 96, 96, 97, 97, 97, 97, 97, 98, 98, 98, 98, 98, 99, 99, 99, 99,
  99, 99, 99, 99, 100, 100, 100, 100, 100, 100, 100, 100, 100, 100, 100, 100, 100, 100, 100, 100,
  100, 100, 100, 100, 99, 99, 99, 99, 99, 99, 99, 99, 98, 98, 98, 98, 98, 98, 97, 97,
  97, 97, 96, 96, 96, 96, 95, 95, 95, 94, 94, 94, 93, 93, 93, 92, 92, 92, 91, 91,
  90, 90, 89, 89, 89, 88, 88, 87, 87, 86, 86, 85, 85, 84, 84, 83, 82, 82, 81, 81,
  80, 80, 79, 78, 78, 77, 76, 76, 75, 74, 74, 73, 72, 72, 71, 70, 69, 69, 68, 67,
  66, 66, 65, 64, 63, 62, 62, 61, 60, 59, 58, 57, 56, 56, 55, 54, 53, 52, 51, 50,
  49, 48, 47, 46, 45, 44, 43, 42, 41, 40, 39, 38, 37, 36, 35, 34, 33, 31, 30, 29,
  28, 27, 26, 25, 23, 22, 21, 20, 19, 17, 16, 15, 14, 12, 11, 10, 9, 7, 6, 5,
  3, 2, 1
} ;

const uint8_t MAXWAVE = 36;

class Waveform {
  public:
    Waveform(void) {
      wavep = 0;
    }

    void record(int waveval) {
      waveval = waveval / 8;       // scale to fit in byte
      waveval += 128;              //shift so entired waveform is +ve
      waveval = waveval < 0 ? 0 : waveval;
      waveform[wavep] = (uint8_t) (waveval > 255) ? 255 : waveval;
      wavep = (wavep + 1) % MAXWAVE;
    }

    void scale() {
      uint8_t maxw = 0;
      uint8_t minw = 255;
      for (int i = 0; i < MAXWAVE; i++) {
        maxw = waveform[i] > maxw ? waveform[i] : maxw;
        minw = waveform[i] < minw ? waveform[i] : minw;
      }
      uint8_t scale8 = (maxw - minw) / 4 + 1; //scale * 8 to preserve precision
      uint8_t index = wavep;
      for (int i = 0; i < MAXWAVE; i++) {
        disp_wave[i] = 31 - ((uint16_t)(waveform[index] - minw) * 8) / scale8;
        index = (index + 1) % MAXWAVE;
      }
    }


  private:
    uint8_t waveform[MAXWAVE];
    uint8_t disp_wave[MAXWAVE];
    uint8_t wavep = 0;

} wave;


uint8_t flag = 0;
int  beatAvg;
int  SPO2;//, SPO2f;

//bool filter_for_graph = false;
bool draw_Red = false;

bool tag_found = false;
static const unsigned long frequency  = 5000;
unsigned long previous = 0;

bool TEMPStaus = false;
bool SPO2Staus = false;

bool TEMPTOut = false;
bool SPO2TOut = false;

const int numReadings = 10;
int average_hbcount = 0;
int average_spo2 = 0;
float average_temp = 0;

long lastBeat = 0;    //Time of the last beat
long displaytime = 0; //Time of the last display update

bool mob_found = false;
bool valid_user = false;
int time_out_kb = 0;

int8_t espo2 = 0;
float etemp = 0;
int8_t ehbcount = 0;

bool DevType = false;
bool DevVldSt = false;
bool DevUpSt = false;
bool Proto = false;

char *random1 = "";
String random2 = "";

String qstatus = "";
String qrandom1 = "";
String qrandom2 = "";
String qhbcount = "";
String qspo2 = "";
String qtemp = "";
String qdevtype = "";

String esrvname = "";
String epcol = "";

const char * qerandom1 = "";
const char *  qerandom2 = "";
const char *  qereason = "";

//I2C Address
//LCD =0x27
//MLX90614=0x57
//MAX30100=0x5A

const int analogInPin = A0;
static const uint8_t RLED = D0;
static const uint8_t GLED = D8;
static const uint8_t BUZ = D9;
static const uint8_t RLY = D10;

int sensorValue = 0;        // value read from the pot

//Establishing Local server at port 80 whenever required
ESP8266WebServer server(80);

String userid = "";
String username = "";
bool dataresp = false;
String flagst = "";
String Uflagst = "";

//Function Decalration
bool testWifi(void);
void launchWeb(void);
void setupAP(void);

void err_rled_buz_3();
void ok_gled_buz_2();
void err_data_rgled_buz_4();

void lcdprintChar(char t);

int i = 0;
int statusCode;
String st = "";
String content = "";



//String getMAC()
//{
//  uint8_t mac[6];
//  char result[14];
//  WiFi.macAddress(mac);
//  snprintf( result, sizeof( result ), "%02x%02x%02x%02x%02x%02x", mac[ 0 ], mac[ 1 ], mac[ 2 ], mac[ 3 ], mac[ 4 ], mac[ 5 ] );
//  return String( result );
//}

//String getDevID()
//{
//  unsigned long chipID = ESP.getChipId();
//  String devID = String(chipID, HEX);
//  return devID;
//}



void checkForUpdates()
{
  String fwURL = String ("http://") + esrvname.c_str() + fwURLLoc + devType;
  String fwVersionURL = fwURL;
  fwVersionURL.concat( ".ver" );
  Serial.println( fwVersionURL );

  Serial.println( "Checking for firmware updates." );
  //  Serial.print( "chipID: " );
  //  Serial.println( devID );
  Serial.print( "Firmware version URL: " );
  Serial.println( fwVersionURL );

  WiFiClient client;
  HTTPClient httpClient;

  httpClient.begin(client , fwVersionURL );

  int httpCode = httpClient.GET();
  Serial.print("httpCode ");
  Serial.println(httpCode);

  if ( httpCode == 200 )
  {
    Serial.print( "Current Model Number: ");
    Serial.println( MODEL );
    Serial.print( "Current firmware version: " );
    Serial.println( VERSION );

    String verFileContents = httpClient.getString();
    Serial.print( "Available model/firmware version from File: " );
    Serial.println(verFileContents);

    int lengthData = verFileContents.length();
    char testIt = verFileContents.charAt(lengthData - 2);
    if (testIt == 13)
    {
      lengthData = lengthData - 2;
    }
    int comma = verFileContents.indexOf(",");
    String newModel = verFileContents.substring(0, comma);
    String newVersion = verFileContents.substring(comma + 1, lengthData);

    newVersion.trim();
    newModel.trim();

    Serial.print( "New Model Number: ");
    Serial.println( newModel );
    Serial.print( "New Version: ");
    Serial.println( newVersion );

    if ( VERSION  != newVersion)
    {
      Serial.println( "Preparing to update" );
      // Constuct URL for new firmware
      String fwImageURL = fwURL;
      fwImageURL.concat( ".bin" );
      Serial.print( "Firmware Image File URL: ");
      Serial.println(fwImageURL);

      // Update the firmware
      t_httpUpdate_return ret = ESPhttpUpdate.update( client , fwImageURL);

      // Error handling
      switch (ret)
      {
        case HTTP_UPDATE_FAILED:
          Serial.printf("HTTP_UPDATE_FAILED Error (%d): %s", ESPhttpUpdate.getLastError(), ESPhttpUpdate.getLastErrorString().c_str());
          Serial.println(" ");
          break;

        case HTTP_UPDATE_NO_UPDATES:
          Serial.println("HTTP_UPDATE_NO_UPDATES");
          break;
      }
    }


    else
    {
      Serial.println( "Already on latest version" );
    }
  }
  else
  {
    Serial.print( "Firmware version check failed, HTTP response code: " );
    Serial.println( httpCode );
  }
  httpClient.end();

} //end of void checkForUpdates()


// A single, global CertStore which can be used by all
// connections.  Needs to stay live the entire time any of
// the WiFiClientBearSSLs are present.
BearSSL::CertStore certStore;

// Set time via NTP, as required for x.509 validation
void setClock() {
  configTime(3 * 3600, 0, "pool.ntp.org", "time.nist.gov");

  Serial.print("Waiting for NTP time sync: ");
  time_t now = time(nullptr);
  while (now < 8 * 3600 * 2) {
    delay(500);
    Serial.print(".");
    now = time(nullptr);
  }
  Serial.println("");
  struct tm timeinfo;
  gmtime_r(&now, &timeinfo);
  Serial.print("Current time: ");
  Serial.print(asctime(&timeinfo));
}



//FOR KEYBORD KEY PRINT  AND UPDATE
void lcdprintChar(char t) { // display char on lcd and Serial

  if (t == ' ')
  {
    memset(MobNo, 0, sizeof(MobNo));
    lcd.clear();
    lcd.setCursor(0, 0);
    lcd.print("Pls Enter Valid ");
    lcd.setCursor(0, 1);
    lcd.print(" Mobile Number  ");
    delay(2000);
    lcd.clear();
    x = 0; y = 0;
    lcd.setCursor(x, y);
  }
  else {
    MobNo[x] = t;
#ifdef _DEBUG
    Serial.print(t);
#endif
    x++;
  }

  if (x > 10) {
    memset(MobNo, 0, sizeof(MobNo));
    lcd.clear();
    x = 0; y = 0;
    lcd.setCursor(x, y);
  }

}


bool testWifi(void)
{
  int c = 0;
#ifdef _DEBUG
  Serial.println("Waiting for Wifi to connect");
#endif
  while ( c < 20 ) {
    if (WiFi.status() == WL_CONNECTED)
    {
      return true;
    }
    delay(500);
#ifdef _DEBUG
    Serial.print("*");
#endif
    c++;
  }
#ifdef _DEBUG
  Serial.println("");
  Serial.println("Connect timed out, opening AP");
#endif

  return false;
}

void launchWeb()
{
#ifdef _DEBUG
  Serial.println("");
#endif
  if (WiFi.status() == WL_CONNECTED) {
#ifdef _DEBUG
    Serial.println("WiFi connected");
#endif
  }
#ifdef _DEBUG
  Serial.print("Local IP: ");
  Serial.println(WiFi.localIP());
  Serial.print("SoftAP IP: ");
  Serial.println(WiFi.softAPIP());
#endif
  createWebServer(); // Start the server
  server.begin();
#ifdef _DEBUG
  Serial.println("Server started");
#endif
}

void setupAP(void)
{
  WiFi.mode(WIFI_STA);
  WiFi.disconnect();
  delay(100);
  int n = WiFi.scanNetworks();
#ifdef _DEBUG
  Serial.println("scan done");
#endif
  if (n == 0) {
#ifdef _DEBUG
    Serial.println("no networks found");
#endif
  }
  else
  {
#ifdef _DEBUG
    Serial.print(n);
    Serial.println("networks found");
#endif
    for (int i = 0; i < n; ++i)
    {
      // Print SSID and RSSI for each network found
#ifdef _DEBUG
      Serial.print(i + 1);
      Serial.print(": ");
      Serial.print(WiFi.SSID(i));
      Serial.print(" (");
      Serial.print(WiFi.RSSI(i));
      Serial.print(")");
      Serial.println((WiFi.encryptionType(i) == ENC_TYPE_NONE) ? " " : "*");
#endif
      delay(10);
    }
  }

#ifdef _DEBUG
  Serial.println("");
#endif

  st = "<ol>";
  for (int i = 0; i < n; ++i)
  {
    // Print SSID and RSSI for each network found
    st += "<li>";
    st += WiFi.SSID(i);
    st += " (";
    st += WiFi.RSSI(i);

    st += ")";
    st += (WiFi.encryptionType(i) == ENC_TYPE_NONE) ? " " : "*";
    st += "</li>";
  }
  st += "</ol>";
  delay(100);
  WiFi.softAP("KO AAHAM", "KO AAHAM");
#ifdef _DEBUG
  Serial.println("Initializing_softap_for_wifi credentials_modification");
#endif
  launchWeb();
#ifdef _DEBUG
  Serial.println("over");
#endif
}
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
void loop() {
up:

  const unsigned long fiveMinutes = 5 * 60 * 1000UL;
  static unsigned long lastSampleTime = 0 - fiveMinutes;  // initialize such that a reading is due the first time through loop()

  unsigned long now = millis();
  if (now - lastSampleTime >= fiveMinutes)
  {
    lastSampleTime += fiveMinutes;

    if (WiFi.status() == WL_CONNECTED) { //Check WiFi connection status

      if (Proto)                          /// for HTTP  ///////////
      {
        lcd.clear();
        lcd.setCursor(0, 0);
        lcd.print("DEVICE UPDATE   ");
        delay(1000);
        qstatus = "update";

        DynamicJsonDocument jsonBuffer1(200);

        jsonBuffer1["random1"] = qrandom1;
        jsonBuffer1["random2"] = qrandom2;
        jsonBuffer1["status"] = qstatus;

        //        StaticJsonBuffer<200> jsonBuffer1;
        //        JsonObject& root = jsonBuffer1.createObject();
        //
        //        root["random1"] = qrandom1;
        //        root["random2"] = qrandom2;
        //        root["status"] = qstatus;


        //String dataStr = "";
        //        root.printTo(dataStr);

        BearSSL::WiFiClientSecure *bear = new BearSSL::WiFiClientSecure();

        // Integrate the cert store with this connection
        bear->setCertStore(&certStore);

#ifdef _DEBUG
        Serial.println();
        //Serial.println(dataStr);
        serializeJson(jsonBuffer1, Serial);
        Serial.printf("Attempting to fetch http://");
        Serial.printf(esrvname.c_str());
        Serial.printf("/api/updateDevStatus\n");
#endif
        //serializeJson(jsonBuffer1, dataStr);
        String API_Path = "/api/updateDevStatus";
        fetch_http_POST(esrvname.c_str(), API_Path, jsonBuffer1);
        //fetch_http_POST(esrvname.c_str(), API_Path, dataStr);

        //        if (DevUpSt == false) {
        //          lcd.clear();
        //          lcd.setCursor(0, 0);
        //          lcd.print("DEVICE UPDATE   ");
        //          lcd.setCursor(0, 1);
        //          lcd.print("      FAIL!     ");
        //          err_rled_buz_3();
        //          delay(2000);
        //          goto up;
        //        }
        //        else
        //        {
        //          lcd.setCursor(0, 1);
        //          lcd.print("     UPDATED!   ");
        //          ok_gled_buz_2();
        //          delay(1000);
        //        }

      }
      else {                                 /// for HTTPS  ///////////
        lcd.clear();
        lcd.setCursor(0, 0);
        lcd.print("DEVICE UPDATE   ");
        delay(1000);
        qstatus = "update";

        DynamicJsonDocument jsonBuffer1(200);


        jsonBuffer1["random1"] = qrandom1;
        jsonBuffer1["random2"] = qrandom2;
        jsonBuffer1["status"] = qstatus;


        //        StaticJsonBuffer<200> jsonBuffer1;
        //        JsonObject& root = jsonBuffer1.createObject();
        //
        //        root["random1"] = qrandom1;
        //        root["random2"] = qrandom2;
        //        root["status"] = qstatus;


        //String dataStr = "";
        //        root.printTo(dataStr);

        BearSSL::WiFiClientSecure *bear = new BearSSL::WiFiClientSecure();

        // Integrate the cert store with this connection
        bear->setCertStore(&certStore);

#ifdef _DEBUG
        Serial.println();
        //Serial.println(dataStr);
        Serial.printf("Attempting to fetch https://");
        Serial.printf(esrvname.c_str());
        Serial.printf("/api/updateDevStatus\n");
#endif
        //serializeJson(jsonBuffer1, dataStr);
        String API_Path = "/api/updateDevStatus";
        //fetch_https_POST(bear, esrvname.c_str(), 443, API_Path, dataStr);
        fetch_https_POST(bear, esrvname.c_str(), 443, API_Path, jsonBuffer1);
        delete bear;

        //        if (DevUpSt == false) {
        //          lcd.clear();
        //          lcd.setCursor(0, 0);
        //          lcd.print("DEVICE UPDATE   ");
        //          lcd.setCursor(0, 1);
        //          lcd.print("      FAIL!     ");
        //          err_rled_buz_3();
        //          delay(2000);
        //          goto up;
        //        }
        //        else
        //        {
        //          lcd.setCursor(0, 1);
        //          lcd.print("     UPDATED!   ");
        //          ok_gled_buz_2();
        //          delay(1000);
        //        }
      }

    }
    else {
#ifdef _DEBUG
      Serial.println("WiFi Disconnected");
#endif
      err_data_rgled_buz_4();
      lcd.clear();
      lcd.setCursor(0, 0);
      lcd.print("WiFi Disconnect");
      delay(1000);
      uint8_t time_out = 0;
      while ((WiFi.status() != WL_CONNECTED))
      {
        time_out++;
#ifdef _DEBUG
        Serial.print(".");
#endif
        lcd.setCursor(0, 0);
        lcd.print("WIFI_CONNECTING");
        delay(1000);
        server.handleClient();
        if (time_out >= 60) {// 1 minute time out
          err_data_rgled_buz_4();
          break;
        }
      }
    }
    lcd.clear();
  }

#ifdef _KBRD
  if (!DevType)
  {

    //if (c == ' ') {
    lcd.setCursor(0, 0);
    lcd.print(MobNo);
    lcd.setCursor(0, 1);
    lcd.print("Enter Mobile NO ");
    // }

    // read the next key
    c = kpd.getKey();
    delay(10);
    if (c) {

      //#ifdef _DEBUG
      //      Serial.println(c);
      //#endif

      // check for some of the special keys
      if (c == 'E') {
        uint8_t i;

        for (i = 0; i < 11; i++)
        {
          if (MobNo[i] == '\0')
            break;
        }

        if (i < 10)
        {
#ifdef _DEBUG
          Serial.println();
          Serial.println("Mobile No Not Valid");
#endif
          memset(MobNo, 0, sizeof(MobNo));
          lcd.clear();
          lcd.setCursor(0, 0);
          lcd.print("  Mobile Number ");
          lcd.setCursor(0, 1);
          lcd.print("  is Not Valid  ");
          x = 0; y = 0;
          lcd.setCursor(x, y);
          delay(2000);
          lcd.clear();
          goto up;
        }
        else
        {
          lcd.clear();
          lcd.setCursor(0, 0);
          lcd.print("Saved Mobile No ");
          lcd.setCursor(0, 1);
          lcd.print(MobNo);
#ifdef _DEBUG
          Serial.println();
          Serial.println(MobNo);
#endif
          userid = MobNo;
        }
        delay(2000);

        while (1)
        {
          // read the next key
          c = kpd.getKey();
          delay(10);
          if (c) {
            Serial.println(c);

#ifdef _DEBUG
            Serial.println(c);
#endif
            // check for some of the special keys
            if (c == 'E') {
#ifdef _DEBUG
              Serial.println(F("\n[ENT]\n"));
#endif
              valid_user = true;
              lcd.clear();
              break;
            }
            else if (c == 'C') {
#ifdef _DEBUG
              Serial.println(F("\n[ESC]\n"));
#endif
              memset(MobNo, 0, sizeof(MobNo));
              lcd.clear();
              lcd.setCursor(0, 1);
              lcd.print("Enter Mobile NO ");
              x = 0; y = 0;
              lcd.setCursor(x, y);
              goto up;
            }

            time_out_kb++;
            delay(1000);
            if (time_out_kb >= 20) { // 1 minute time out
              err_rled_buz_3();
              x = 0; y = 0;
              lcd.clear();
              lcd.setCursor(x, y);
              goto up;
            }
          }
        }
      }


      else if (c == 'C') {
#ifdef _DEBUG
        Serial.println(F("\n[ESC]\n"));
#endif
        memset(MobNo, 0, sizeof(MobNo));
        lcd.clear();
        lcd.setCursor(0, 1);
        lcd.print("Enter Mobile NO ");
        x = 0; y = 0;
        lcd.setCursor(x, y);
      }

      else {
        // otherwise, just print all normal characters
        lcdprintChar(c);
      }
    }
  }
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

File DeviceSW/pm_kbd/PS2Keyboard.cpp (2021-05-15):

/*
  PS2Keyboard.cpp - PS2Keyboard library
  Copyright (c) 2007 Free Software Foundation.  All right reserved.
  Written by Christian Weichel <info@32leaves.net>

  ** Mostly rewritten Paul Stoffregen <paul@pjrc.com> 2010, 2011
  ** Modified for use beginning with Arduino 13 by L. Abraham Smith, <n3bah@microcompdesign.com> * 
  ** Modified for easy interrup pin assignement on method begin(datapin,irq_pin). Cuningan <cuninganreset@gmail.com> **

  for more information you can read the original wiki in arduino.cc
  at http://www.arduino.cc/playground/Main/PS2Keyboard
  or http://www.pjrc.com/teensy/td_libs_PS2Keyboard.html

  Version 2.4 (March 2013)
  - Support Teensy 3.0, Arduino Due, Arduino Leonardo & other boards
  - French keyboard layout, David Chochoi, tchoyyfr at yahoo dot fr

  Version 2.3 (October 2011)
  - Minor bugs fixed

  Version 2.2 (August 2011)
  - Support non-US keyboards - thanks to Rainer Bruch for a German keyboard :)

  Version 2.1 (May 2011)
  - timeout to recover from misaligned input
  - compatibility with Arduino "new-extension" branch
  - TODO: send function, proposed by Scott Penrose, scooterda at me dot com

  Version 2.0 (June 2010)
  - Buffering added, many scan codes can be captured without data loss
    if your sketch is busy doing other work
  - Shift keys supported, completely rewritten scan code to ascii
  - Slow linear search replaced with fast indexed table lookups
  - Support for Teensy, Arduino Mega, and Sanguino added

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
  You should have received a copy of the GNU Lesser General Public
  License along with this library; if not, write to the Free Software
  Foundation, Inc., 51 Franklin St, Fifth Floor, Boston, MA  02110-1301  USA
*/

#include "PS2Keyboard.h"

#define BUFFER_SIZE 45
static volatile uint8_t buffer[BUFFER_SIZE];
static volatile uint8_t head, tail;
static uint8_t DataPin;
static uint8_t CharBuffer=0;
static uint8_t UTF8next=0;
static const PS2Keymap_t *keymap=NULL;

// The ISR for the external interrupt
ICACHE_RAM_ATTR void ps2interrupt(void)
{
	static uint8_t bitcount=0;
	static uint8_t incoming=0;
	static uint32_t prev_ms=0;
	uint32_t now_ms;
	uint8_t n, val;

	val = digitalRead(DataPin);
	now_ms = millis();
	if (now_ms - prev_ms > 250) {
		bitcount = 0;
		incoming = 0;
	}
	prev_ms = now_ms;
	n = bitcount - 1;
	if (n <= 7) {
		incoming |= (val << n);
	}
	bitcount++;
	if (bitcount == 11) {
		uint8_t i = head + 1;
		if (i >= BUFFER_SIZE) i = 0;
		if (i != tail) {
			buffer[i] = incoming;
			head = i;
		}
		bitcount = 0;
		incoming = 0;
	}
}

static inline uint8_t get_scan_code(void)
{
	uint8_t c, i;

	i = tail;
	if (i == head) return 0;
	i++;
	if (i >= BUFFER_SIZE) i = 0;
	c = buffer[i];
	tail = i;
	return c;
}

// http://www.quadibloc.com/comp/scan.htm
// http://www.computer-engineering.org/ps2keyboard/scancodes2.html

// These arrays provide a simple key map, to turn scan codes into ISO8859
// output.  If a non-US keyboard is used, these may need to be modified
// for the desired output.
//

const PROGMEM PS2Keymap_t PS2Keymap_US = {
  // without shift
	{0, PS2_F9, 0, PS2_F5, PS2_F3, PS2_F1, PS2_F2, PS2_F12,
	0, PS2_F10, PS2_F8, PS2_F6, PS2_F4, PS2_TAB, '`', 0,
	0, 0 /*Lalt*/, 0 /*Lshift*/, 0, 0 /*Lctrl*/, 'q', '1', 0,
	0, 0, 'z', 's', 'a', 'w', '2', 0,
	0, 'c', 'x', 'd', 'e', '4', '3', 0,
	0, ' ', 'v', 'f', 't', 'r', '5', 0,
	0, 'n', 'b', 'h', 'g', 'y', '6', 0,
	0, 0, 'm', 'j', 'u', '7', '8', 0,
	0, ',', 'k', 'i', 'o', '0', '9', 0,
	0, '.', '/', 'l', ';', 'p', '-', 0,
	0, 0, '\'', 0, '[', '=', 0, 0,
	0 /*CapsLock*/, 0 /*Rshift*/, PS2_ENTER /*Enter*/, ']', 0, '\\', 0, 0,
	0, 0, 0, 0, 0, 0, PS2_BACKSPACE, 0,
	0, '1', 0, '4', '7', 0, 0, 0,
	'0', '.', '2', '5', '6', '8', PS2_ESC, 0 /*NumLock*/,
	PS2_F11, '+', '3', '-', '*', '9', PS2_SCROLL, 0,
	0, 0, 0, PS2_F7 },
  // with shift
	{0, PS2_F9, 0, PS2_F5, PS2_F3, PS2_F1, PS2_F2, PS2_F12,
	0, PS2_F10, PS2_F8, PS2_F6, PS2_F4, PS2_TAB, '~', 0,
	0, 0 /*Lalt*/, 0 /*Lshift*/, 0, 0 /*Lctrl*/, 'Q', '!', 0,
	0, 0, 'Z', 'S', 'A', 'W', '@', 0,
	0, 'C', 'X', 'D', 'E', '$', '#', 0,
	0, ' ', 'V', 'F', 'T', 'R', '%', 0,
	0, 'N', 'B', 'H', 'G', 'Y', '^', 0,
	0, 0, 'M', 'J', 'U', '&', '*', 0,
	0, '<', 'K', 'I', 'O', ')', '(', 0,
	0, '>', '?', 'L', ':', 'P', '_', 0,
	0, 0, '"', 0, '{', '+', 0, 0,
	0 /*CapsLock*/, 0 /*Rshift*/, PS2_ENTER /*Enter*/, '}', 0, '|', 0, 0,
	0, 0, 0, 0, 0, 0, PS2_BACKSPACE, 0,
	0, '1', 0, '4', '7', 0, 0, 0,
	'0', '.', '2', '5', '6', '8', PS2_ESC, 0 /*NumLock*/,
	PS2_F11, '+', '3', '-', '*', '9', PS2_SCROLL, 0,
	0, 0, 0, PS2_F7 },
	0
};
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

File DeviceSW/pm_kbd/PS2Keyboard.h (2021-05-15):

/*
  PS2Keyboard.h - PS2Keyboard library
  Copyright (c) 2007 Free Software Foundation.  All right reserved.
  Written by Christian Weichel <info@32leaves.net>

  ** Mostly rewritten Paul Stoffregen <paul@pjrc.com>, June 2010
  ** Modified for use with Arduino 13 by L. Abraham Smith, <n3bah@microcompdesign.com> * 
  ** Modified for easy interrup pin assignement on method begin(datapin,irq_pin). Cuningan <cuninganreset@gmail.com> **

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
  You should have received a copy of the GNU Lesser General Public
  License along with this library; if not, write to the Free Software
  Foundation, Inc., 51 Franklin St, Fifth Floor, Boston, MA  02110-1301  USA
*/


#ifndef PS2Keyboard_h
#define PS2Keyboard_h

#if defined(ARDUINO) && ARDUINO >= 100
#include "Arduino.h" // for attachInterrupt, FALLING
#else
#include "WProgram.h"
#endif

#include "int_pins.h"

// Every call to read() returns a single byte for each
// keystroke.  These configure what byte will be returned
// for each "special" key.  To ignore a key, use zero.
#define PS2_TAB				9
#define PS2_ENTER			13
#define PS2_BACKSPACE			127
#define PS2_ESC				27
#define PS2_INSERT			0
#define PS2_DELETE			127
#define PS2_HOME			0
#define PS2_END				0
#define PS2_PAGEUP			25
#define PS2_PAGEDOWN			26
#define PS2_UPARROW			11
#define PS2_LEFTARROW			8
#define PS2_DOWNARROW			10
#define PS2_RIGHTARROW			21
#define PS2_F1				0
#define PS2_F2				0
#define PS2_F3				0
#define PS2_F4				0
#define PS2_F5				0
#define PS2_F6				0
#define PS2_F7				0
#define PS2_F8				0
#define PS2_F9				0
#define PS2_F10				0
#define PS2_F11				0
#define PS2_F12				0
#define PS2_SCROLL			0
#define PS2_EURO_SIGN			0

#define PS2_INVERTED_EXCLAMATION	161 // ¡
#define PS2_CENT_SIGN			162 // ¢
#define PS2_POUND_SIGN			163 // £
#define PS2_CURRENCY_SIGN		164 // ¤
#define PS2_YEN_SIGN			165 // ¥
#define PS2_BROKEN_BAR                 	166 // ¦
#define PS2_SECTION_SIGN		167 // §
#define PS2_DIAERESIS			168 // ¨
#define PS2_COPYRIGHT_SIGN		169 // ©
#define PS2_FEMININE_ORDINAL		170 // ª
#define PS2_LEFT_DOUBLE_ANGLE_QUOTE	171 // «
#define PS2_NOT_SIGN			172 // ¬
#define PS2_HYPHEN			173
#define PS2_REGISTERED_SIGN		174 // ®
#define PS2_MACRON			175 // ¯
#define PS2_DEGREE_SIGN			176 // °
#define PS2_PLUS_MINUS_SIGN		177 // ±
#define PS2_SUPERSCRIPT_TWO		178 // ²
#define PS2_SUPERSCRIPT_THREE		179 // ³
#define PS2_ACUTE_ACCENT		180 // ´
#define PS2_MICRO_SIGN			181 // µ
#define PS2_PILCROW_SIGN		182 // ¶
#define PS2_MIDDLE_DOT			183 // ·
#define PS2_CEDILLA			184 // ¸
#define PS2_SUPERSCRIPT_ONE		185 // ¹
#define PS2_MASCULINE_ORDINAL		186 // º
#define PS2_RIGHT_DOUBLE_ANGLE_QUOTE	187 // »
#define PS2_FRACTION_ONE_QUARTER	188 // ¼
#define PS2_FRACTION_ONE_HALF		189 // ½
#define PS2_FRACTION_THREE_QUARTERS	190 // ¾
#define PS2_INVERTED_QUESTION_MARK	191 // ¿
#define PS2_A_GRAVE			192 // À
#define PS2_A_ACUTE			193 // Á
#define PS2_A_CIRCUMFLEX		194 // Â
#define PS2_A_TILDE			195 // Ã
#define PS2_A_DIAERESIS			196 // Ä
#define PS2_A_RING_ABOVE		197 // Å
#define PS2_AE				198 // Æ
#define PS2_C_CEDILLA			199 // Ç
#define PS2_E_GRAVE			200 // È
#define PS2_E_ACUTE			201 // É
#define PS2_E_CIRCUMFLEX		202 // Ê
#define PS2_E_DIAERESIS			203 // Ë
#define PS2_I_GRAVE			204 // Ì
#define PS2_I_ACUTE			205 // Í
#define PS2_I_CIRCUMFLEX		206 // Î
#define PS2_I_DIAERESIS			207 // Ï
#define PS2_ETH				208 // Ð
#define PS2_N_TILDE			209 // Ñ
#define PS2_O_GRAVE			210 // Ò
#define PS2_O_ACUTE			211 // Ó
#define PS2_O_CIRCUMFLEX		212 // Ô
#define PS2_O_TILDE			213 // Õ
#define PS2_O_DIAERESIS			214 // Ö
#define PS2_MULTIPLICATION		215 // ×
#define PS2_O_STROKE			216 // Ø
#define PS2_U_GRAVE			217 // Ù
#define PS2_U_ACUTE			218 // Ú
#define PS2_U_CIRCUMFLEX		219 // Û
#define PS2_U_DIAERESIS			220 // Ü
#define PS2_Y_ACUTE			221 // Ý
#define PS2_THORN			222 // Þ
#define PS2_SHARP_S			223 // ß
#define PS2_a_GRAVE			224 // à
#define PS2_a_ACUTE			225 // á
#define PS2_a_CIRCUMFLEX		226 // â
#define PS2_a_TILDE			227 // ã
#define PS2_a_DIAERESIS			228 // ä
#define PS2_a_RING_ABOVE		229 // å
#define PS2_ae				230 // æ
#define PS2_c_CEDILLA			231 // ç
#define PS2_e_GRAVE			232 // è
#define PS2_e_ACUTE			233 // é
#define PS2_e_CIRCUMFLEX		234 // ê
#define PS2_e_DIAERESIS			235 // ë
#define PS2_i_GRAVE			236 // ì
#define PS2_i_ACUTE			237 // í
#define PS2_i_CIRCUMFLEX		238 // î
#define PS2_i_DIAERESIS			239 // ï
#define PS2_eth				240 // ð
#define PS2_n_TILDE			241 // ñ
#define PS2_o_GRAVE			242 // ò
#define PS2_o_ACUTE			243 // ó
#define PS2_o_CIRCUMFLEX		244 // ô
#define PS2_o_TILDE			245 // õ
#define PS2_o_DIAERESIS			246 // ö
#define PS2_DIVISION			247 // ÷
#define PS2_o_STROKE			248 // ø
#define PS2_u_GRAVE			249 // ù
#define PS2_u_ACUTE			250 // ú
#define PS2_u_CIRCUMFLEX		251 // û
#define PS2_u_DIAERESIS			252 // ü
#define PS2_y_ACUTE			253 // ý
#define PS2_thorn			254 // þ
#define PS2_y_DIAERESIS			255 // ÿ


#define PS2_KEYMAP_SIZE 136
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

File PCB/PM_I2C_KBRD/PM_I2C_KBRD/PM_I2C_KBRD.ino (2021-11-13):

// I2C Keypad for Arduino
// Venkateswara Rao.E 
// 19-oct-2015
// Credits to  @author Alexander Brevig

#include <Wire.h>
#include "Keypad_I2C.h"
#include <Keypad.h>
#define I2CADDR 0x27

const byte ROWS = 4; //four rows
const byte COLS = 3; //three columns
char keys[ROWS][COLS] = {
  {'1','2','3'},
  {'4','5','6'},
  {'7','8','9'},
  {'*','0','#'}
};

// Digitran keypad, bit numbers of PCF8574 i/o port
byte rowPins[ROWS] = {0, 1, 2, 4}; //connect to the row pinouts of the keypad
byte colPins[COLS] = {5, 6, 7}; //connect to the column pinouts of the keypad

Keypad_I2C kpd( makeKeymap(keys), rowPins, colPins, ROWS, COLS, I2CADDR, PCF8574 );

void setup(){
    Wire.begin( );
    kpd.begin( makeKeymap(keys) );
    Serial.begin(115200);
    Serial.println( "start" );
}

void loop(){
    char key = kpd.getKey();
    
    if (key){
    Serial.println(key);
    }
}

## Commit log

2020-11-27 Added folders to store device firmware, Enclosure and PCB
2020-11-27 Added Version 2 of the permit me enclosure
    [KOAHAM D8.1 - BACK COVER KO-AHAM TECH 4-1.STL, outer_cover_ko-aham_tech_4.stl]
2021-01-01 Add all my files
    [Permitme_main _sub_V1-B_Cu.gbr, Permitme_main _sub_V1-B_Mask.gbr, Permitme_main _sub_V1-B_Paste.gbr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]
2021-01-02 Adding latest version of enclosure design
    [back_cover_ko-aham_tech_4.IGS, back_cover_ko-aham_tech_4.STL, outer_cover_ko-aham_tech_4.stl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]
2021-01-02 Added enclosure 3p printer files
    [KOAHAM D8.1 - BACK COVER KO-AHAM TECH 4-1.STL, back_cover_ko-aham_tech_4.IGS, back_cover_ko-aham_tech_4.STL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]
2021-05-18 added test script for iotController and added device type
2021-08-05 Bus fixes and billing functionality disabled
    [DEVID_TOCKEN_LCD_V5.ino, Permit-Me_V5.ino]
2021-10-07 V7-I2C KPD, V8-DEV Setup serial
2021-11-13 added keypad pcb
    [BACK COVER .stp, KEYBORD_PCB_V1-B.Cu.dxf, KEYBORD_PCB_V1-B.Mask.dxf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]
